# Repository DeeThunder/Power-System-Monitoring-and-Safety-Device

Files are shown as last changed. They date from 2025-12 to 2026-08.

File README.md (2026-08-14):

# Power System Monitoring and Safety Device - README

## Overview

This is a **Smart Energy Monitoring and Safety System** designed for residential areas in Nigeria. The system monitors power parameters (Voltage, Current, Power), displays data locally on an OLED screen, transmits data to the cloud via Blynk, and includes automatic safety protection that disconnects power during fault conditions.

> This project was professionally designed and implemented as a **Final Year Project (FYP)** for a client, focusing on robust industrial-grade monitoring principles and cloud-integrated data analytics.

## Features

✅ **Real-time Monitoring**: Continuous voltage, current, and power measurement  
✅ **Cloud Dashboard**: Blynk IoT integration for remote monitoring  
✅ **Cloud Logging**: Automatic logging to Google Sheets for historical data analysis  
✅ **Local Display**: 1.3" OLED screen showing live data  
✅ **Safety Protection**: Automatic relay trip on over-voltage, under-voltage, or over-current  
✅ **Offline Operation**: Continues monitoring and protection even without WiFi  
✅ **Battery Monitoring**: Track system uptime and battery health via heartbeat logging  
✅ **Visual Status**: RGB LED indicates system state  
✅ **Modular Architecture**: Clean C++ design with separated concerns  
✅ **Non-blocking**: Uses millis() timers, no delay() calls

## Hardware Components

- **Microcontroller**: ESP32 Dev Kit
- **Voltage Sensor**: ZMPT101b (simulated with potentiometer for testing)
- **Current Sensor**: SCT-013 100A CT (simulated with potentiometer for testing)
- **Relay**: 1-Channel Relay Module
- **Display**: 1.3" OLED (SSD1306, I2C)
- **Status LED**: RGB LED (Common Cathode)
- **Power Control**: Physical Boat Switch (hardware power on/off)
- **Power**: AC-DC 5V with 7.4V battery backup

## Pin Configuration

| Component | GPIO Pin | Notes |
| --- | --- | --- |
| Voltage Sensor  | GPIO 34  | ADC1_CH6 |
| Current Sensor  | GPIO 35  | ADC1_CH7 |
| Relay | GPIO 26  | Configurable Active HIGH/LOW |
| RGB LED (Red) | GPIO 25  | PWM capable |
| RGB LED (Green) | GPIO 33  | PWM capable |
| RGB LED (Blue)  | GPIO 32  | PWM capable |
| OLED SDA | GPIO 21  | I2C Data |
| OLED SCL | GPIO 22  | I2C Clock |

## Software Architecture

### Modules

1. **EnergySensor**: Handles sensor reading with calibration
2. **DisplayManager**: Manages OLED display screens
3. **NetworkManager**: WiFi and Blynk communication
4. **SafetyManager**: Threshold monitoring and relay control
5. **CloudLogger**: Automatic logging to Google Sheets
6. **PerformanceLogger**: CSV logging via Serial and cloud integration
7. **StateManager**: Finite state machine coordinating all modules

### State Machine

- **STATE_BOOT**: Initialization and WiFi connection
- **STATE_NORMAL**: Active monitoring with cloud logging
- **STATE_TRIP_PROTECTION**: Fault detected, power disconnected
- **STATE_OFFLINE_MODE**: WiFi lost, local monitoring continues

## Getting Started

Install [PlatformIO](https://platformio.org/) IDE or CLI.

### Configure Credentials

**IMPORTANT:** Create your `secrets.h` file by moving the template from the `docs` folder:

```bash
# Move the template to the include folder and rename it
copy docs/secrets.h.example include/secrets.h  # On Windows
# OR
cp docs/secrets.h.example include/secrets.h    # On Linux/Mac
```

Edit `include/secrets.h` and update your credentials:

```cpp
// WiFi Credentials
#define SECRET_WIFI_SSID      "Your_WiFi_Name"
#define SECRET_WIFI_PASSWORD  "Your_WiFi_Password"

// Blynk IoT Credentials  
#define SECRET_BLYNK_TEMPLATE_ID     "Your_Template_ID"
#define SECRET_BLYNK_TEMPLATE_NAME   "Your_Template_Name"
#define SECRET_BLYNK_AUTH_TOKEN      "Your_Blynk_Token"

// Google Sheets Logging
#define SECRET_GOOGLE_SHEETS_URL     "https://script.google.com/macros/s/YOUR_DEPLOYMENT_ID/exec"
```

> **Note:** `secrets.h` is already in `.gitignore` and will NOT be committed to version control.

### Configure Safety Thresholds

Adjust thresholds in `include/config.h`:

```cpp
#define VOLTAGE_MAX           240.0  // Over-voltage trip
#define VOLTAGE_MIN           180.0  // Under-voltage trip
#define CURRENT_MAX           20.0   // Over-current trip
```

### Build and Upload

```bash
pio run --target upload
pio device monitor
```

## Blynk Setup

> **[Click here for the detailed Step-by-Step Blynk Setup Guide](BLYNK_SETUP.md)**

### Virtual Pins

- **V0**: Voltage (read-only)
- **V1**: Current (read-only)
- **V2**: Power (read-only)
- **V3**: System State (read-only)
- **V4**: Reset Button (write)

### Datastreams

Create the following datastreams in your Blynk template:

1. V0 - Voltage (0-300V)
2. V1 - Current (0-100A)
3. V2 - Power (0-10000W)
4. V3 - State (String)
5. V4 - Reset (Integer 0-1)

## Cloud Logging (Google Sheets)

The system automatically logs performance data and system events to Google Sheets when WiFi is connected.

### Setup Google Apps Script

1. **Create a Google Sheet** named "ESP32 Performance Logs"
2. **Create 4 tabs**: `SystemEvents`, `Latency`, `Accuracy`, `TripResponse`
3. **Open Script Editor**: Extensions → Apps Script
4. **Paste the script** from `docs/google_apps_script.js`
5. **Deploy as Web App**:
   - Click Deploy → New deployment
   - Type: Web app
   - Execute as: Me
   - Who has access: Anyone
   - Click Deploy
   - **Copy the deployment URL**

### Configure in ESP32

Edit `include/config.h`:

```cpp
#define GOOGLE_SHEETS_URL "https://script.google.com/macros/s/YOUR_DEPLOYMENT_URL/exec"
#define ENABLE_CLOUD_LOGGING      // Enables automatic cloud logging
#define ENABLE_PERFORMANCE_LOGGING // Enables performance metrics
```

### What Gets Logged

**SystemEvents Tab:**
- BOOT - System startup
- HEARTBEAT - Every 5 minutes (includes WiFi RSSI for battery health monitoring)
- POWER_OUTAGE - Mains voltage lost
- POWER_RESTORED - Mains voltage restored
- TRIP - Safety faults with fault reason

**Latency Tab:**
- Sensor read time
- Blynk transmit time
- Total latency (logged on every Blynk transmission)

**Accuracy Tab:**
- Voltage, Current, Power readings
- Logged every 10 seconds

**TripResponse Tab:**
- Fault detection time
- Relay trip time
- Total response time (logged when safety trips occur)

### Battery Health Monitoring

Use heartbeat data to monitor battery health:

- **Continuous heartbeats during outage** = Healthy battery
- **Gaps in heartbeats** = Battery depleted or WiFi too weak
- **Declining RSSI** = Battery voltage dropping
- **BOOT after gap** = System shut down (battery dead)

## Calibration

After hardware assembly, calibrate sensors:

1. Connect a known voltage source (measure with multimeter)
2. Adjust `VOLTAGE_SLOPE` and `VOLTAGE_INTERCEPT` in `config.h`
3. Connect a known current load (measure with clamp meter)
4. Adjust `CURRENT_SLOPE` and `CURRENT_INTERCEPT` in `config.h`
5. Verify accuracy across operating range

## Safety Features

### Automatic Protection

The system continuously monitors power parameters every 100ms. If any threshold is exceeded:

1. Relay trips immediately (power disconnected)
2. RGB LED turns RED
3. OLED displays fault reason
4. Alert sent to Blynk (if connected)

### Reset Procedure

To reset after a trip:

1. Ensure fault condition is cleared
2. Press reset button in Blynk app

The system will only reset if readings are within safe limits.

### Offline Safety

**Critical**: Safety monitoring continues even when WiFi is disconnected. The relay will trip on fault conditions regardless of network status.

## RGB LED Status

- 🔵 **Blue**: Booting/Initializing
- 🟢 **Green**: Normal operation
- 🟡 **Yellow**: Offline mode (WiFi disconnected)
- 🔴 **Red**: Trip protection active

## Troubleshooting

### Display Not Working

- Check I2C address (0x3C or 0x3D)
- Verify SDA/SCL connections
- Check serial monitor for initialization errors

### WiFi Not Connecting

- Verify credentials in `config.h`
- Check 2.4GHz WiFi (ESP32 doesn't support 5GHz)
- Monitor serial output for connection attempts

### Blynk Not Connecting

- Verify auth token
- Ensure WiFi is connected first
- Check Blynk server status

### False Trips

- Adjust hysteresis values in `config.h`
- Calibrate sensors properly
- Check for electrical noise

## Migration to Production

To switch from simulation (potentiometers) to real sensors:

1. Remove `-D SIMULATION_MODE` from `platformio.ini`
2. Add EmonLib library
3. Update `EnergySensor.cpp` with EmonLib code
4. Recalibrate with actual sensors

## Documentation

### 📚 Complete Documentation Suite

- **[API Documentation](docs/API_DOCUMENTATION.md)** - Complete API reference, configuration guide, calibration procedures, and troubleshooting
- **[Technical Challenges Report](docs/TECHNICAL_CHALLENGES.md)** - Detailed analysis of all challenges faced and solutions implemented
- **[Blynk Setup Guide](BLYNK_SETUP.md)** - Step-by-step IoT platform configuration
- **[Hybrid Analysis Guide](docs/HYBRID_ANALYSIS_GUIDE.md)** - Guide for combining cloud and USB data for unified analysis

### Quick Links

| Topic | Document | Description |
|---|---|---|
| Getting Started | [API Documentation](docs/API_DOCUMENTATION.md#getting-started) | Installation and first-time setup |
| API Reference | [API Documentation](docs/API_DOCUMENTATION.md#api-reference) | Complete class and method documentation |
| Calibration | [API Documentation](docs/API_DOCUMENTATION.md#calibration-procedures) | Sensor calibration step-by-step |
| Troubleshooting | [API Documentation](docs/API_DOCUMENTATION.md#troubleshooting) | Common issues and solutions |
| Contributing | [API Documentation](docs/API_DOCUMENTATION.md#contributing) | Code style and contribution guidelines |
| Future Plans | [API Documentation](docs/API_DOCUMENTATION.md#future-enhancements) | Roadmap and planned features |

## License

MIT License - Free for educational and commercial use

## Support

For issues or questions, please open an issue on GitHub.

---

**⚠️ Safety Warning**: This system controls mains power. Only qualified electricians should install and wire the hardware. Improper installation can result in electric shock, fire, or death.

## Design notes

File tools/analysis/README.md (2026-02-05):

# Performance Analysis Scripts

This folder contains Python scripts for analyzing the performance data collected from the Smart Energy Monitoring System.

## Data Files

The analysis scripts process the following CSV files from the performance_data directory:
- `../../performance_data/latency.csv` - Transmission latency measurements
- `../../performance_data/accuracy.csv` - Voltage, current, and power accuracy measurements
- `../../performance_data/trip_response.csv` - Safety trip response time data

## Analysis Scripts

### 1. `latency_analysis.py`
Analyzes transmission latency metrics:
- Sensor read time distribution
- Blynk transmission delays
- Total end-to-end latency
- Temporal trends and anomaly detection
- Component breakdown and bottleneck identification

### 2. `accuracy_analysis.py`
Evaluates measurement accuracy:
- Voltage sensor calibration validation
- Current sensor accuracy assessment
- Statistical error metrics (MAE, RMSE, MAPE)
- Noise and stability analysis
- Sensor drift over time

### 3. `trip_response_analysis.py`
Assesses safety protection performance:
- Fault detection time analysis
- Relay actuation time statistics
- Total response time distribution
- Safety compliance validation
- Reliability metrics

### 4. `integrated_analysis.py`
Performs multi-metric correlation analysis:
- Relationships between latency, accuracy, and response time
- System-wide performance assessment
- Comprehensive reporting

### 5. `generate_report.py`
Generates comprehensive performance report:
- Executive summary with key findings
- Detailed analysis results
- Visualizations and charts
- Recommendations for optimization

## Requirements

Install required Python packages:
```bash
pip install pandas numpy matplotlib seaborn scipy scikit-learn
```

Or use the provided requirements file:
```bash
pip install -r requirements.txt
```

## Usage

**Note: Do not run these scripts yet until sufficient data is collected.**

Once you have adequate data:

```bash
# Run individual analyses
python latency_analysis.py
python accuracy_analysis.py
python trip_response_analysis.py

# Run integrated analysis
python integrated_analysis.py

# Generate comprehensive report
python generate_report.py
```

## Output

Analysis results will be saved in the `results/` subdirectory:
- `results/figures/` - Generated plots and visualizations
- `results/tables/` - Statistical summary tables
- `results/reports/` - Comprehensive analysis reports

## Data Collection Guidelines

For robust analysis, collect:
- **Latency data**: At least 1000 samples across different conditions
- **Accuracy data**: Reference measurements with calibrated instruments
- **Trip response data**: Multiple fault scenarios (over-voltage, under-voltage, over-current)

## Analysis Plan

Refer to `../../docs/PERFORMANCE_ANALYSIS_PLAN.md` for the complete analysis methodology and objectives.

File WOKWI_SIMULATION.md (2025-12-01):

# Wokwi Simulation Guide

## Overview

This project includes a complete Wokwi simulation that allows you to test the Smart Energy Monitoring System in your browser without physical hardware!

## Simulation Components

The simulation includes:
- ✅ **ESP32 DevKit V1**
- ✅ **SSD1306 OLED Display** (128x64, I2C)
- ✅ **2x Potentiometers** (simulating voltage and current sensors)
- ✅ **Relay Module** (1-channel)
- ✅ **RGB LED** (Common Cathode with 220Ω resistors)

## How to Run the Simulation

### Option 1: Wokwi for VS Code Extension

1. **Install Extension**:
   - Open VS Code
   - Install "Wokwi Simulator" extension
   - Restart VS Code

2. **Build Firmware**:
   ```bash
   # In VS Code terminal
   pio run
   ```

3. **Start Simulation**:
   - Press `F1` or `Ctrl+Shift+P`
   - Type "Wokwi: Start Simulator"
   - Select the project

4. **Interact**:
   - Adjust potentiometers to simulate voltage/current changes
   - Watch OLED display update
   - Observe RGB LED color changes
   - Monitor serial output

### Option 2: Wokwi CLI

1. **Install Wokwi CLI**:
   ```bash
   npm install -g @wokwi/cli
   ```

2. **Build Firmware**:
   ```bash
   pio run
   ```

3. **Run Simulation**:
   ```bash
   wokwi-cli --timeout 0
   ```

### Option 3: Wokwi Web (Manual Upload)

1. Go to [https://wokwi.com/](https://wokwi.com/)
2. Create new ESP32 project
3. Copy `diagram.json` content to the diagram editor
4. Upload your compiled firmware
5. Start simulation

## Testing Scenarios

### 1. Normal Operation Test

**Steps**:
1. Start simulation
2. Wait for OLED to show startup screen (3 seconds)
3. System should transition to NORMAL state
4. RGB LED should be **GREEN**
5. OLED should display voltage, current, and power readings

**Expected Behavior**:
- Voltage: ~180-250V (based on potentiometer position)
- Current: ~0-25A (based on potentiometer position)
- Power: Voltage × Current
- Display updates every 1 second

### 2. Over-Voltage Trip Test

**Steps**:
1. Wait for system to enter NORMAL state
2. Slowly turn the **voltage potentiometer** to maximum (right)
3. Watch for voltage reading to exceed 240V

**Expected Behavior**:
- Relay clicks (trips)
- RGB LED turns **RED**
- OLED displays "ALERT! OVER VOLTAGE"
- Serial monitor shows fault detection
- System enters TRIP_PROTECTION state

### 3. Over-Current Trip Test

**Steps**:
1. Reset simulation (or wait for Blynk reset)
2. Wait for NORMAL state
3. Turn the **current potentiometer** to maximum (right)
4. Watch for current reading to exceed 20A

**Expected Behavior**:
- Relay trips
- RGB LED turns **RED**
- OLED displays "ALERT! OVER CURRENT"
- System enters TRIP_PROTECTION state

### 4. Under-Voltage Trip Test

**Steps**:
1. Reset simulation
2. Wait for NORMAL state
3. Turn the **voltage potentiometer** to minimum (left)
4. Watch for voltage reading to drop below 180V

**Expected Behavior**:
- Relay trips
- RGB LED turns **RED**
- OLED displays "ALERT! UNDER VOLTAGE"
- System enters TRIP_PROTECTION state

### 5. Offline Mode Test

**Note**: WiFi simulation in Wokwi is limited. The system will likely enter OFFLINE_MODE automatically since there's no real WiFi network.

**Expected Behavior**:
- RGB LED turns **YELLOW**
- OLED shows "OFFLINE MODE"
- Safety monitoring continues
- System can still trip on faults

## Serial Monitor Commands

Watch the serial monitor for debug output:

```
[EnergySensor] V=220.50V, I=5.23A, P=1153.22W
[SafetyManager] All checks passed
[DisplayManager] Showing data screen
[NetworkManager] WiFi disconnected
[StateManager] State: OFFLINE_MODE
```

## Potentiometer Mapping

### Voltage Potentiometer (GPIO 34)
- **Minimum (Left)**: ~180V
- **Center**: ~215V
- **Maximum (Right)**: ~250V

### Current Potentiometer (GPIO 35)
- **Minimum (Left)**: ~0A
- **Center**: ~12.5A
- **Maximum (Right)**: ~25A

## Triggering Safety Trips

To test each safety feature:

| Fault Type | Potentiometer | Position | Threshold |
|---|---|---|---|
| Over-Voltage | Voltage | Maximum (Right) | >240V |
| Under-Voltage | Voltage | Minimum (Left) | <180V |
| Over-Current | Current | Maximum (Right) | >20A |

## Reset After Trip

Since the physical button was removed, you have two options to reset:

1. **Restart Simulation**: Stop and start the simulation
2. **Blynk Integration**: If you configure Blynk, use the V4 reset button

## Limitations in Simulation

⚠️ **What doesn't work in Wokwi**:
- WiFi connection (will always be in OFFLINE_MODE)
- Blynk communication
- Real-time cloud data logging

✅ **What works perfectly**:
- Sensor reading (via potentiometers)
- Safety threshold checking
- Relay trip mechanism
- RGB LED status indication
- OLED display updates
- State machine transitions
- Serial debug output

## Troubleshooting

### Display Not Showing
- Check I2C address in `config.h` (should be 0x3C)
- Verify OLED connections in `diagram.json`

### Relay Not Clicking
- Ensure potentiometer values exceed thresholds
- Check serial monitor for safety check messages

### RGB LED Not Changing
- Verify Common Cathode configuration in `config.h`
- Check resistor connections in diagram

### Simulation Crashes
- Reduce `ADC_SAMPLES` in `config.h` to 5 (from 10)
- Increase task intervals to reduce CPU load

## Advanced: Modifying the Simulation

### Change Voltage Range

Edit `EnergySensor.cpp`, line ~75:
```cpp
float simulatedVoltage = map(rawADC, 0, ADC_RESOLUTION, 180, 250);
//                                                        ^^^  ^^^
//                                                        min  max
```

### Change Current Range

Edit `EnergySensor.cpp`, line ~88:
```cpp
float simulatedCurrent = map(rawADC, 0, ADC_RESOLUTION, 0, 25);
//                                                       ^  ^^
//                                                      min max
```

### Add More Components

Edit `diagram.json` to add:
- Push buttons
- Additional LEDs
- LCD display
- Buzzers

## Video Recording

Wokwi allows you to record your simulation:
1. Start simulation
2. Click "Record" button
3. Perform test scenarios
4. Stop recording
5. Download video

Perfect for documentation and demonstrations!

## Next Steps

After validating in Wokwi:
1. ✅ Verify all state transitions work
2. ✅ Test safety thresholds
3. ✅ Confirm display updates
4. 🔧 Build on real hardware
5. 🔧 Calibrate with actual sensors
6. 🔧 Configure WiFi and Blynk

---

**Happy Simulating!** 🚀

For issues or questions, check the serial monitor output first - it provides detailed debug information about what the system is doing.

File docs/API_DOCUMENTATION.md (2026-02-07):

# Smart Energy Monitoring & Safety System - Complete Documentation

## Table of Contents
1. [Project Overview](#project-overview)
2. [System Architecture](#system-architecture)
3. [Getting Started](#getting-started)
4. [API Reference](#api-reference)
5. [Configuration Guide](#configuration-guide)
6. [Calibration Procedures](#calibration-procedures)
7. [Troubleshooting](#troubleshooting)
8. [Contributing](#contributing)
9. [Future Enhancements](#future-enhancements)
10. [License](#license)

---

## Project Overview

### Purpose
A real-time energy monitoring system with intelligent safety protection for AC electrical loads. The system monitors voltage and current, calculates power consumption, and automatically disconnects the load when dangerous conditions are detected.

### Key Features
- ✅ Real-time voltage and current monitoring
- ✅ Automatic over/under voltage protection
- ✅ Over-current protection with configurable thresholds
- ✅ OLED display for local monitoring
- ✅ IoT connectivity via Blynk platform
- ✅ RGB LED status indicators
- ✅ Smart power-off detection (no false trips)
- ✅ Exponential moving average filtering for stability
- ✅ Hysteresis to prevent relay chattering

### Hardware Requirements
- **Microcontroller**: ESP32 Development Board
- **Voltage Sensor**: ZMPT101B AC Voltage Sensor
- **Current Sensor**: SCT-013 Current Transformer (30A max)
- **Display**: SSD1306 128x64 OLED (I2C)
- **Relay**: 1-Channel 5V Relay Module (NO contact)
- **Status LED**: RGB LED (Common Cathode)
- **Power Supply**: 5V DC adapter

### Software Stack
- **Framework**: Arduino (PlatformIO)
- **Platform**: Espressif ESP32
- **Libraries**:
  - `Blynk` (v1.3.2) - IoT connectivity
  - `U8g2` (v2.36.15) - OLED display driver
  - `WiFi` - Built-in ESP32 WiFi
  - `Wire` - I2C communication

---

## System Architecture

### Module Overview

```
┌─────────────────────────────────────────────────────────┐
│                     Main Application                     │
│                      (main.cpp)                          │
└──────────────────────┬──────────────────────────────────┘
                       │
                       ▼
┌─────────────────────────────────────────────────────────┐
│                    State Manager                         │
│           (Finite State Machine Coordinator)             │
└─┬───────┬───────┬───────┬───────────────────────────────┘
  │       │       │       │
  ▼       ▼       ▼       ▼
┌────┐ ┌────┐ ┌────┐ ┌─────────┐
│Sensor│Display│Safety│ Network │
│Module│Module │Module│ Module  │
└────┘ └────┘ └────┘ └─────────┘
  │       │       │       │
  ▼       ▼       ▼       ▼
┌────────────────────────────────┐
│      Hardware Abstraction      │
│   (ADC, I2C, GPIO, WiFi)       │
└────────────────────────────────┘
```

### State Machine

The system operates in four distinct states:

1. **BOOT**: Initialization and WiFi connection
2. **NORMAL**: Active monitoring with cloud connectivity
3. **OFFLINE_MODE**: Local monitoring (WiFi unavailable)
4. **TRIP_PROTECTION**: Fault detected, relay disconnected

### Data Flow

```
Sensors → ADC → RMS Calculation → Smoothing → Safety Check → Relay Control
                                      ↓
                                  Display Update
                                      ↓
                                  Cloud Publish
```

---

## Getting Started

### Prerequisites

1. **Install PlatformIO**
   ```bash
   # Using VS Code
   # Install PlatformIO IDE extension from marketplace
   
   # Or using CLI
   pip install platformio
   ```

2. **Clone Repository**
   ```bash
   git clone https://github.com/yourusername/Samuel-Project.git
   cd Samuel-Project
   ```

3. **Configure Credentials**
   
   Create `include/secret.h`:
   ```cpp
   #ifndef SECRET_H
   #define SECRET_H
   
   #define SECRET_WIFI_SSID "YourWiFiSSID"
   #define SECRET_WIFI_PASSWORD "YourWiFiPassword"
   
   #endif
   ```

4. **Update Blynk Configuration**
   
   In `include/config.h`, update:
   ```cpp
   #define BLYNK_TEMPLATE_ID "YourTemplateID"
   #define BLYNK_AUTH_TOKEN "YourAuthToken"
   ```

### Building and Uploading

```bash
# Build project
pio run

# Upload to ESP32
pio run --target upload

# Open serial monitor
pio device monitor
```

### First-Time Setup

1. **Power on the system**
2. **Wait for WiFi connection** (blue LED indicates connecting)
3. **Verify display shows startup screen**
4. **Check serial monitor for initialization logs**
5. **Proceed to calibration** (see Calibration section)

---

## API Reference

### EnergySensor Class

**Purpose**: Handles voltage and current sensing with RMS calculation and filtering.

#### Public Methods

```cpp
void begin()
```
- **Description**: Initialize ADC and sensor configuration
- **Parameters**: None
- **Returns**: void
- **Usage**:
  ```cpp
  EnergySensor sensor;
  sensor.begin();
  ```

```cpp
void update()
```
- **Description**: Read sensors, calculate RMS, apply smoothing
- **Call Frequency**: Every 500ms recommended
- **Side Effects**: Updates internal voltage_ and current_ values

```cpp
float getVoltage() const
```
- **Returns**: Smoothed voltage in Volts (V)
- **Range**: 0.0 - 300.0V
- **Accuracy**: ±2% after calibration

```cpp
float getCurrent() const
```
- **Returns**: Smoothed current in Amperes (A)
- **Range**: 0.0 - 30.0A
- **Accuracy**: ±5% after calibration

```cpp
float getPower() const
```
- **Returns**: Calculated power (V × I) in Watts (W)
- **Note**: Assumes unity power factor

```cpp
bool isValid() const
```
- **Returns**: true if readings are within reasonable bounds
- **Use Case**: Validate sensor connectivity

#### Private Methods

```cpp
float readVoltageSimulation()
```
- **Algorithm**: Single-pass RMS with dynamic DC bias removal
- **Samples**: 1000 samples over ~100ms
- **Formula**: `RMS = sqrt((ΣV² - (ΣV)²/N) / N)`

```cpp
float readCurrentSimulation()
```
- **Algorithm**: Two-pass RMS (DC bias then RMS)
- **Samples**: 500 samples over ~100ms

---

### SafetyManager Class

**Purpose**: Monitors electrical parameters and controls relay for protection.

#### Public Methods

```cpp
void begin()
```
- **Description**: Initialize relay and RGB LED pins
- **Initial State**: Relay OFF, RGB Blue

```cpp
bool checkSafety(float voltage, float current)
```
- **Parameters**:
  - `voltage`: Current voltage reading (V)
  - `current`: Current current reading (A)
- **Returns**: `true` if safe, `false` if fault detected
- **Side Effects**: Sets `lastFaultReason_` on fault
- **Logic**:
  ```
  IF voltage < 100V THEN return true (power off)
  IF voltage > 250V THEN return false (over-voltage)
  IF voltage < 216V THEN return false (under-voltage)
  IF current > 30A THEN return false (over-current)
  ELSE return true
  ```

```cpp
void tripRelay()
```
- **Description**: De-energize relay (disconnect load)
- **Visual**: Sets RGB to RED
- **State**: Sets `relayTripped_ = true`

```cpp
void resetRelay()
```
- **Description**: Energize relay (connect load)
- **Precondition**: Safety conditions must be met
- **State**: Sets `relayTripped_ = false`

```cpp
bool isTripped() const
```
- **Returns**: Current relay state
- **Use Case**: Check if system is in fault state

```cpp
String getLastFaultReason() const
```
- **Returns**: "OVER VOLTAGE", "UNDER VOLTAGE", or "OVER CURRENT"
- **Use Case**: Display fault reason to user

```cpp
void setRGBStatus(uint8_t r, uint8_t g, uint8_t b)
```
- **Parameters**: RGB values (0-255)
- **Note**: Automatically inverts for common anode LEDs
- **Predefined Colors**:
  - `RGB_BLUE`: Booting/Offline
  - `RGB_GREEN`: Normal operation
  - `RGB_RED`: Fault/Trip
  - `RGB_YELLOW`: Warning (unused)

---

### DisplayManager Class

**Purpose**: Manages OLED display output for various system states.

#### Public Methods

```cpp
bool begin()
```
- **Returns**: `true` if display initialized successfully
- **Display**: SSD1306 128x64 I2C
- **Address**: 0x3C

```cpp
void showStartup()
```
- **Display**: Logo and loading bar
- **Duration**: Shown during BOOT state (~3s)

```cpp
void showData(float voltage, float current, float power, 
              bool wifiConnected, bool blynkConnected)
```
- **Layout**:
  ```
  ┌────────────────────────┐
  │ ACTIVE [WiFi][Blynk]   │
  ├────────────────────────┤
  │ VOLT                   │
  │      223.5 V           │
  ├────────────────────────┤
  │ CURR     │  PWR        │
  │ 12.5 A   │  2.8 kW     │
  └────────────────────────┘
  ```

```cpp
void showTripAlert(const String& reason)
```
- **Display**: Inverted screen with "TRIPPED!" and fault reason
- **Visual**: High contrast for attention

```cpp
void showOfflineMode()
```
- **Display**: "OFFLINE MODE" with local sensor data
- **Use Case**: WiFi disconnected

```cpp
void clear()
```
- **Description**: Clear display buffer and screen

---

### StateManager Class

**Purpose**: Coordinates all modules using finite state machine.

#### Public Methods

```cpp
void begin()
```
- **Description**: Initialize state machine
- **Initial State**: BOOT

```cpp
void update()
```
- **Description**: Execute current state logic
- **Call Frequency**: Every loop iteration
- **Non-blocking**: Uses millis() for timing

```cpp
void setState(SystemState newState)
```
- **Parameters**: `STATE_BOOT`, `STATE_NORMAL`, `STATE_OFFLINE_MODE`, `STATE_TRIP_PROTECTION`
- **Side Effects**: Calls `onStateExit()` and `onStateEnter()`

```cpp
SystemState getState() const
```
- **Returns**: Current system state

```cpp
String getStateName() const
```
- **Returns**: Human-readable state name

```cpp
void handleReset()
```
- **Description**: Handle manual reset from button or Blynk
- **Precondition**: Must be in TRIP_PROTECTION state
- **Safety Check**: Verifies conditions are safe before reset

```cpp
void handleManualSwitch(bool turnOn)
```
- **Description**: Handle manual ON/OFF control via Blynk switch (V5)
- **Parameters**:
  - `turnOn`: `true` to turn load ON, `false` to turn OFF
- **Behavior**:
  - **Turn ON**: Performs safety check first. If safe, energizes relay and sets LED to green. If unsafe, denies request and syncs switch back to OFF.
  - **Turn OFF**: Immediately de-energizes relay, sets LED to blinking orange, and sends notification.
- **State Persistence**: Manual OFF state is saved to EEPROM and restored after power loss
- **Visual Indicator**: Blinking orange LED indicates manual OFF state
- **Safety**: Cannot turn ON if conditions are unsafe

```cpp
void handleMasterOverride(bool enable)
```
- **Description**: Enable/disable Master Override mode to bypass safety protection
- **Parameters**:
  - `enable`: `true` to enable override, `false` to disable
- **⚠️ WARNING**: This bypasses ALL safety checks except extreme overcurrent (150% of max)
- **Behavior**:
  - **Enable**: 
    - Bypasses safety checks
    - Energizes relay immediately
    - Sets LED to yellow (solid)
    - Transitions from TRIP state to NORMAL/OFFLINE
    - Syncs Blynk switch to ON
    - Sends hazard warning notification
    - Periodic reminders every 30 minutes
  - **Disable**:
    - Restores safety protection
    - Checks current conditions
    - If unsafe: Trips immediately and transitions to TRIP_PROTECTION
    - If safe: Maintains relay ON, sets LED to green/blue
- **State Persistence**: Override state is saved to EEPROM and restored after power loss
- **Visual Indicator**: Yellow LED (solid) indicates override active
- **Extreme Overcurrent Protection**: Override auto-disables if current exceeds 150% of CURRENT_MAX (fire prevention)
- **Use Case**: Temporary operation during maintenance or testing when conditions are known to be outside normal limits
- **Virtual Pin**: V5 (Blynk switch)

#### State Update Methods (Private)

```cpp
void updateStateBoot()
```
- **Timing**: 3s startup delay
- **Transition**: → NORMAL (WiFi OK) or OFFLINE_MODE (timeout)

```cpp
void updateStateNormal()
```
- **Tasks**:
  - Read sensors (500ms interval)
  - Check safety (100ms interval)
  - Update display (1000ms interval)
  - Publish to Blynk (2000ms interval)
- **Transitions**:
  - → TRIP_PROTECTION (fault detected)
  - → OFFLINE_MODE (WiFi lost)

```cpp
void updateStateTripProtection()
```
- **Tasks**:
  - Continue sensor reading
  - Display fault alert
  - Publish fault to cloud
- **Transition**: → NORMAL/OFFLINE (manual reset + safe)

```cpp
void updateStateOfflineMode()
```
- **Tasks**:
  - Local monitoring continues
  - Attempt WiFi reconnection
  - Safety checks active
- **Transitions**:
  - → NORMAL (WiFi restored)
  - → TRIP_PROTECTION (fault detected)

---

### NetworkManager Class

**Purpose**: Handle WiFi and Blynk cloud connectivity.

#### Public Methods

```cpp
void begin()
```
- **Description**: Start WiFi connection
- **Non-blocking**: Connection happens in background

```cpp
void update()
```
- **Description**: Maintain WiFi and Blynk connections
- **Call Frequency**: Every loop iteration
- **Tasks**:
  - Monitor WiFi status
  - Run Blynk.run()
  - Attempt reconnection if needed

```cpp
void publishData(float voltage, float current, float power)
```
- **Description**: Send sensor data to Blynk
- **Throttling**: Internal 2s minimum interval
- **Virtual Pins**:
  - V0: Voltage
  - V1: Current
  - V2: Power

```cpp
void sendAlert(const String& message)
```
- **Description**: Send push notification via Blynk
- **Event**: "safety_alert"
- **Use Case**: Fault detection

```cpp
void updateState(const String& state)
```
- **Description**: Update system state on cloud
- **Virtual Pin**: V3

```cpp
bool isWiFiConnected() const
```
- **Returns**: WiFi connection status

```cpp
bool isBlynkConnected() const
```
- **Returns**: Blynk cloud connection status

```cpp
void setResetCallback(void (*callback)())
```
- **Description**: Register callback for Blynk reset button
- **Virtual Pin**: V4 (write)

---

## Configuration Guide

### config.h Reference

#### Pin Definitions

```cpp
// Analog Sensors (ADC1 only - ADC2 conflicts with WiFi)
#define PIN_VOLTAGE_SENSOR    34  // GPIO 34
#define PIN_CURRENT_SENSOR    35  // GPIO 35

// Digital Outputs
#define PIN_RELAY             26  // GPIO 26
#define PIN_RGB_RED           25  // GPIO 25
#define PIN_RGB_GREEN         33  // GPIO 33
#define PIN_RGB_BLUE          32  // GPIO 32

// I2C (OLED Display)
#define PIN_SDA               21  // GPIO 21
#define PIN_SCL               22  // GPIO 22
```

**⚠️ Important**: Do not use ADC2 pins (GPIO 0, 2, 4, 12-15, 25-27) for analog input when WiFi is active.

#### Safety Thresholds

```cpp
// Voltage Limits
#define VOLTAGE_MAX           250.0  // Over-voltage trip (V)
#define VOLTAGE_MIN           216.0  // Under-voltage trip (V)
#define VOLTAGE_HYSTERESIS    5.0    // Prevent chattering (V)
#define VOLTAGE_POWER_PRESENT_THRESHOLD 100.0  // Power detection (V)

// Current Limits
#define CURRENT_MAX           30.0   // Over-current trip (A)
#define CURRENT_HYSTERESIS    0.5    // Prevent chattering (A)
```

**Customization Guide**:
- **VOLTAGE_MAX**: Set to 110% of nominal voltage (e.g., 230V × 1.1 = 253V)
- **VOLTAGE_MIN**: Set to 90% of nominal voltage (e.g., 230V × 0.9 = 207V)
- **CURRENT_MAX**: Set to rated current of protected load
- **HYSTERESIS**: 2-5V for voltage, 0.5-1A for current

#### Calibration Constants

```cpp
// Voltage Sensor (ZMPT101B)
#define VOLTAGE_CALIBRATION_FACTOR  556.0  // Adjust based on calibration
#define VOLTAGE_NOISE_THRESHOLD     75.0   // Ghost voltage filter (V)

// Current Sensor (SCT-013)
#define CURRENT_NOISE_THRESHOLD     0.60   // Ghost current filter (A)
```

**Calibration Formula**:
```
Calibration Factor = Actual Value (multimeter) / Raw RMS (serial log)
```

#### Timing Intervals

```cpp
#define INTERVAL_SENSOR_READ  500    // Sensor reading (ms)
#define INTERVAL_DISPLAY      1000   // Display update (ms)
#define INTERVAL_BLYNK        2000   // Blynk publish (ms)
#define INTERVAL_SAFETY       100    // Safety check (ms) - CRITICAL
#define INTERVAL_WIFI_RETRY   30000  // WiFi reconnect (ms)
```

**Performance Tuning**:
- Decrease `INTERVAL_SAFETY` for faster fault detection (min: 50ms)
- Increase `INTERVAL_BLYNK` to reduce cloud traffic
- Adjust `INTERVAL_SENSOR_READ` based on load dynamics

---

## Calibration Procedures

### Voltage Sensor Calibration

**Required Equipment**:
- Calibrated multimeter (True RMS)
- Stable AC power source

**Procedure**:

1. **Enable Debug Logging**
   - Ensure `#define APP_DEBUG` is uncommented in code
   - Upload firmware and open serial monitor (115200 baud)

2. **Measure Reference Voltage**
   ```
   Connect multimeter to AC source
   Record reading (e.g., 228.5V)
   ```

3. **Read Raw RMS**
   ```
   Look for log line:
   [EnergySensor] Voltage RMS: 0.4105V -> 228.27V AC
                                ^^^^^^
                                This is Raw RMS
   ```

4. **Calculate Calibration Factor**
   ```
   Factor = Actual Voltage / Raw RMS
   Factor = 228.5 / 0.4105 = 556.6
   ```

5. **Update Configuration**
   ```cpp
   // In config.h
   #define VOLTAGE_CALIBRATION_FACTOR  556.6
   ```

6. **Verify**
   ```
   Re-upload firmware
   Check that displayed voltage matches multimeter
   Tolerance: ±2%
   ```

### Current Sensor Calibration

**Required Equipment**:
- Calibrated clamp meter or current meter
- Known resistive load (e.g., heater, incandescent bulb)

**Procedure**:

1. **Connect Known Load**
   ```
   Use purely resistive load (no motors/transformers)
   Measure actual current with clamp meter
   Record reading (e.g., 5.2A)
   ```

2. **Read Raw RMS**
   ```
   Check serial monitor for current RMS value
   (May need to add debug logging similar to voltage)
   ```

3. **Calculate Factor**
   ```
   Factor = Actual Current / Raw RMS
   ```

4. **Update Code**
   ```cpp
   // In EnergySensor.cpp, readCurrentSimulation()
   float calibrationFactor = 20.0;  // Update this value
   ```

5. **Test Multiple Loads**
   ```
   Verify accuracy at:
   - Low current (1-5A)
   - Medium current (5-15A)
   - High current (15-30A)
   ```

### Threshold Calibration

**Noise Floor Measurement**:

1. **Power OFF Test**
   ```
   Disconnect AC input
   Record voltage/current readings
   Should be 0.0V / 0.0A
   If not, increase NOISE_THRESHOLD
   ```

2. **Power ON Test**
   ```
   Connect normal AC
   Monitor for 5 minutes
   Record min/max voltage fluctuations
   Set VOLTAGE_MIN/MAX with margin
   ```

3. **Trip Test**
   ```
   Manually trigger each condition:
   - Over-voltage: Use variable transformer
   - Under-voltage: Reduce input voltage
   - Over-current: Connect high load
   
   Verify relay trips correctly
   Verify reset works when safe
   ```

---

## Troubleshooting

### Common Issues

#### 1. Voltage Reads 0V When Power is ON

**Symptoms**:
```
[EnergySensor] Voltage RMS: 0.0441V -> 0.00V AC
```

**Causes**:
- ZMPT101B gain too low
- Wiring issue
- Sensor not receiving AC input

**Solutions**:
1. **Check Wiring**
   ```
   ZMPT101B OUT → ESP32 GPIO 34
   ZMPT101B VCC → 5V
   ZMPT101B GND → GND
   AC Wire → ZMPT101B Input Terminals
   ```

2. **Adjust Gain**
   ```
   Turn blue potentiometer CLOCKWISE
   Monitor serial output
   Target: Raw RMS = 0.4-0.5V
   ```

3. **Verify AC Input**
   ```
   Use multimeter on ZMPT101B input
   Should read mains voltage (e.g., 230V)
   ```

#### 2. System Trips When Power is Turned OFF

**Symptoms**:
- Relay trips immediately when AC disconnected
- State changes to TRIP_PROTECTION

**Cause**:
- EMA smoothing causing slow voltage decay
- Power-present detection not working

**Solution**:
```cpp
// Verify in EnergySensor.cpp
if (rawVoltage < VOLTAGE_NOISE_THRESHOLD) {
    voltage_ = 0.0;  // Should reset immediately
}

// Verify in SafetyManager.cpp
if (voltage < VOLTAGE_POWER_PRESENT_THRESHOLD) {
    return true;  // Should skip voltage checks
}
```

#### 3. WiFi Won't Connect

**Symptoms**:
```
[NetworkManager] WiFi disconnected
System stuck in BOOT state
```

**Solutions**:
1. **Check Credentials**
   ```cpp
   // In secret.h
   #define SECRET_WIFI_SSID "CorrectSSID"  // Case-sensitive!
   #define SECRET_WIFI_PASSWORD "CorrectPassword"
   ```

2. **Check WiFi Band**
   ```
   ESP32 only supports 2.4GHz
   Ensure router has 2.4GHz enabled
   ```

3. **Increase Timeout**
   ```cpp
   // In config.h
   #define WIFI_CONNECT_TIMEOUT  30000  // Increase to 30s
   ```

#### 4. Display Not Working

**Symptoms**:
- Blank screen
- Initialization failed message

**Solutions**:
1. **Check I2C Address**
   ```cpp
   // In config.h
   #define SCREEN_ADDRESS 0x3C  // Try 0x3D if 0x3C fails
   ```

2. **Scan I2C Bus**
   ```cpp
   // Add to setup()
   Wire.begin(PIN_SDA, PIN_SCL);
   for (byte i = 0; i < 127; i++) {
       Wire.beginTransmission(i);
       if (Wire.endTransmission() == 0) {
           Serial.printf("Found device at 0x%02X\n", i);
       }
   }
   ```

3. **Check Wiring**
   ```
   SDA → GPIO 21
   SCL → GPIO 22
   VCC → 3.3V (not 5V!)
   GND → GND
   ```

#### 5. Relay Chattering

**Symptoms**:
- Relay clicks rapidly on/off
- Voltage near threshold

**Cause**:
- Insufficient hysteresis
- Noisy voltage readings

**Solutions**:
1. **Increase Hysteresis**
   ```cpp
   #define VOLTAGE_HYSTERESIS 10.0  // Increase from 5.0
   ```

2. **Increase Smoothing**
   ```cpp
   // In EnergySensor.cpp
   const float alpha = 0.1;  // Decrease from 0.2 (more smoothing)
   ```

### Debug Logging

**Enable Verbose Logging**:
```cpp
// In config.h
#define APP_DEBUG  // Uncomment this line

// For even more detail
#define DEBUG_SERIAL  // Uncomment for sensor-level logs
```

**Serial Monitor Settings**:
- Baud Rate: 115200
- Line Ending: Both NL & CR
- Filter: None

**Key Log Messages**:
```
[Main] Initialization complete
[StateManager] State transition: BOOT -> NORMAL
[EnergySensor] Voltage RMS: 0.4105V -> 228.27V AC
[SafetyManager] FAULT: Under-voltage detected (215.30V)
[NetworkManager] WiFi connected!
[NetworkManager] Published to Blynk: V=228.50, I=12.30, P=2810.95
```

---

## Contributing

### Code Style Guidelines

**Naming Conventions**:
```cpp
// Classes: PascalCase
class EnergySensor { };

// Methods: camelCase
void updateSensor();

// Private members: camelCase with trailing underscore
float voltage_;

// Constants: UPPER_SNAKE_CASE
#define VOLTAGE_MAX 250.0

// Local variables: camelCase
float currentValue;
```

**File Organization**:
```
include/
  ├── ModuleName.h      // Class declaration
  └── config.h          // Configuration constants

src/
  ├── ModuleName.cpp    // Class implementation
  └── main.cpp          // Application entry point
```

**Documentation**:
```cpp
/**
 * @brief Brief description of function
 * 
 * Detailed description if needed.
 * 
 * @param paramName Description of parameter
 * @return Description of return value
 * 
 * @note Important notes
 * @warning Warnings about usage
 */
void functionName(int paramName);
```

### Adding New Features

**1. Create Feature Branch**
```bash
git checkout -b feature/new-feature-name
```

**2. Implement Feature**
- Follow existing module structure
- Add unit tests if applicable
- Update documentation

**3. Test Thoroughly**
- Unit tests
- Integration tests
- Hardware validation

**4. Submit Pull Request**
- Clear description
- Reference any issues
- Include test results

### Module Extension Example

**Adding a New Sensor**:

1. **Create Header** (`include/NewSensor.h`):
```cpp
#ifndef NEW_SENSOR_H
#define NEW_SENSOR_H

class NewSensor {
public:
    void begin();
    void update();
    float getValue() const;
    
private:
    float value_;
    float readSensor();
};

#endif
```

2. **Implement** (`src/NewSensor.cpp`):
```cpp
#include "NewSensor.h"
#include "config.h"

void NewSensor::begin() {
    // Initialize sensor
}

void NewSensor::update() {
    value_ = readSensor();
}

float NewSensor::getValue() const {
    return value_;
}

float NewSensor::readSensor() {
    // Sensor reading logic
    return 0.0;
}
```

3. **Integrate** (`src/main.cpp`):
```cpp
#include "NewSensor.h"

NewSensor newSensor;

void setup() {
    newSensor.begin();
}

void loop() {
    newSensor.update();
    float value = newSensor.getValue();
}
```

---

## Future Enhancements

### Planned Features

#### Phase 1: Core Improvements
- [ ] **SD Card Logging**
  - Store historical data locally
  - CSV export for analysis
  - Circular buffer for memory efficiency

- [ ] **Web Server Interface**
  - Local web dashboard (ESP32 as AP)
  - Real-time graphs
  - Configuration via web UI

- [ ] **MQTT Support**
  - Alternative to Blynk
  - Home Assistant integration
  - Custom broker support

#### Phase 2: Advanced Features
- [ ] **Energy Billing**
  - kWh accumulation
  - Cost calculation
  - Monthly reports

- [ ] **Load Scheduling**
  - Time-based relay control
  - Peak/off-peak optimization
  - Programmable schedules

- [ ] **Predictive Maintenance**
  - Trend analysis
  - Anomaly detection
  - Fault prediction

#### Phase 3: Hardware Expansion
- [ ] **Multi-Channel Support**
  - Monitor multiple circuits
  - Individual protection per channel
  - Load balancing

- [ ] **Power Quality Analysis**
  - Harmonic analysis
  - Power factor measurement
  - Frequency monitoring

- [ ] **Battery Backup**
  - UPS functionality
  - Seamless switchover
  - Battery health monitoring

### Scalability Considerations

**Horizontal Scaling** (Multiple Units):
```cpp
// Assign unique device IDs
#define DEVICE_ID "UNIT_001"

// MQTT topic structure
String topic = "energy/" + String(DEVICE_ID) + "/voltage";
```

**Vertical Scaling** (More Features):
```cpp
// Modular architecture allows easy addition
class PowerQualityAnalyzer {
    // New module for advanced features
};
```

**Performance Optimization**:
- Use FreeRTOS tasks for parallel processing
- Implement DMA for ADC sampling
- Optimize display updates (dirty regions)

### Architecture Evolution

**Current**: Monolithic state machine
```
StateManager → All Modules
```

**Future**: Event-driven architecture
```
Event Bus ← Modules publish events
    ↓
Subscribers react to events
```

**Benefits**:
- Loose coupling
- Easier testing
- Plugin architecture

---

## License

This project is licensed under the MIT License - see LICENSE file for details.

---

## Support

### Documentation
- [Technical Challenges Report](docs/TECHNICAL_CHALLENGES.md)
- [Chapter 3: Methodology](docs/CHAPTER3_METHODOLOGY.md)
- [Blynk Setup Guide](BLYNK_SETUP.md)
- [Wokwi Simulation](WOKWI_SIMULATION.md)

### Contact
- **Author**: Samuel
- **Email**: [your-email@example.com]
- **GitHub**: [https://github.com/yourusername/Samuel-Project]

### Acknowledgments
- ESP32 Community
- PlatformIO Team
- Blynk Platform
- U8g2 Library Contributors

---

**Last Updated**: December 2025
**Version**: 1.0.0
**Status**: Production Ready

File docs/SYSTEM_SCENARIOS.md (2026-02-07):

# Complete System Behavior Scenarios - Updated

## Overview

This document covers **all possible scenarios** with the updated system behavior including power notifications, manual control, and offline mode.

---

## Scenario Matrix

| # | Condition | State | Relay | LED | Notifications |
|---|---|---|---|-----|---|
| 1 | Boot + No Mains | NORMAL | OFF | Green | "POWER OUTAGE" (after 3s) |
| 2 | Boot + Mains Good + WiFi | NORMAL | ON | Green | None |
| 3 | Boot + Mains Good + No WiFi | OFFLINE_MODE | ON | Blue | None |
| 4 | Normal Operation | NORMAL | ON | Green | None |
| 5 | Overvoltage (255V) | TRIP | OFF | Red | "OVER VOLTAGE" |
| 6 | Undervoltage (180V) | TRIP | OFF | Red | "UNDER VOLTAGE" |
| 7 | Overcurrent (35A) | TRIP | OFF | Red | "OVER CURRENT" |
| 8 | Power Outage During Normal | NORMAL | Current | Green | "POWER OUTAGE" (after 3s) |
| 9 | Power Restored | NORMAL | Depends | Green | "POWER RESTORED" (after 3s) |
| 10 | Manual Switch OFF | NORMAL | OFF | Orange Blink | "LOAD SWITCHED OFF" |
| 11 | Manual Switch ON | NORMAL | ON | Green | None |
| 12 | WiFi Lost During Normal | OFFLINE_MODE | Current | Blue | None |
| 13 | WiFi Restored | NORMAL | Current | Green | None |
| 14 | Manual OFF + Power Outage | NORMAL | OFF | Orange Blink | Both notifications |
| 15 | Fault + WiFi Lost | TRIP | OFF | Red | Fault notification only |
| 16 | Master Override ENABLED | NORMAL/OFFLINE | ON | Yellow | "MASTER OVERRIDE ENABLED" |
| 17 | Master Override DISABLED (Safe) | NORMAL/OFFLINE | ON | Green/Blue | "Override DISABLED" |
| 18 | Master Override DISABLED (Unsafe) | TRIP | OFF | Red | "Override DISABLED" + Fault |
| 19 | Override + Extreme Overcurrent | TRIP | OFF | Red | "CRITICAL: Extreme overcurrent" |

---

## Detailed Scenarios

### Scenario 1: System Boot with No Mains Power

**Initial Conditions**:
- ESP32 powered on (USB/backup power)
- Mains voltage = 0V
- No load connected

**Timeline**:
```
T+0s:  System boots
       State: BOOT
       LED: Yellow blinking
       Relay: OFF

T+3s:  Boot screen complete
       WiFi connecting...

T+10s: WiFi connected
       State: BOOT → NORMAL
       LED: Yellow → Green
       powerWasPresent_ = TRUE (initial)

T+11s: First voltage reading: 0V
       powerPresent = FALSE
       Power state change detected: TRUE → FALSE
       Start debounce timer

T+14s: Still 0V (debounce complete)
       Notification: "POWER OUTAGE: Mains voltage lost"
       powerWasPresent_ = FALSE
       State: NORMAL (no change)
       LED: Green (no change)
       Relay: OFF (no change)
```

**Result**:
- ✅ State: NORMAL
- ✅ Relay: OFF
- ✅ LED: Green (solid)
- ✅ Notification: "POWER OUTAGE"
- ✅ System ready, waiting for power

---

### Scenario 2: System Boot with Good Mains + WiFi

**Initial Conditions**:
- ESP32 powered on
- Mains voltage = 220V
- WiFi available

**Timeline**:
```
T+0s:  System boots
       State: BOOT
       LED: Yellow blinking

T+3s:  Boot screen complete
       WiFi connecting...

T+8s:  WiFi connected
       State: BOOT → NORMAL
       LED: Yellow → Green
       Relay: OFF → ON (energize)

T+9s:  First voltage reading: 220V
       powerPresent = TRUE
       powerWasPresent_ = TRUE (initial)
       No power state change
       No notification

T+10s: Safety check: PASS
       All readings normal
       State: NORMAL
       Relay: ON
       LED: Green
```

**Result**:
- ✅ State: NORMAL
- ✅ Relay: ON
- ✅ LED: Green (solid)
- ✅ Notification: None
- ✅ System operating normally

---

### Scenario 3: System Boot with Good Mains + No WiFi

**Initial Conditions**:
- ESP32 powered on
- Mains voltage = 220V
- WiFi not available

**Timeline**:
```
T+0s:  System boots
       State: BOOT
       LED: Yellow blinking

T+3s:  Boot screen complete
       WiFi connecting...

T+33s: WiFi timeout (30 seconds)
       State: BOOT → OFFLINE_MODE
       LED: Yellow → Blue
       Relay: OFF → ON (energize)

T+34s: First voltage reading: 220V
       powerPresent = TRUE
       powerWasPresent_ = TRUE
       No power state change
       No notification

T+35s: Safety check: PASS
       State: OFFLINE_MODE
       Relay: ON
       LED: Blue
       Local operation active
```

**Result**:
- ✅ State: OFFLINE_MODE
- ✅ Relay: ON
- ✅ LED: Blue (solid)
- ✅ Notification: None (no internet)
- ✅ Full local functionality

---

### Scenario 4: Normal Operation

**Conditions**:
- Mains: 220V (good)
- Current: 5A (normal)
- WiFi: Connected
- User: No action

**Behavior**:
```
Continuous monitoring:
  Voltage: 220V ✓
  Current: 5A ✓
  Safety: PASS ✓

State: NORMAL
Relay: ON
LED: Green (solid)
Notifications: None
Display: Shows V, I, P
Blynk: Updates every 1 second
```

**Result**:
- ✅ Everything normal
- ✅ No notifications
- ✅ Continuous monitoring

---

### Scenario 5: Overvoltage Fault

**Initial Conditions**:
- Normal operation (220V)
- Voltage suddenly rises to 255V

**Timeline**:
```
T+0s:  Voltage: 220V → 255V
       Safety check: checkOverVoltage(255V)
       255V > 249V = TRUE
       Fault detected!

T+0s:  State: NORMAL → TRIP_PROTECTION
       Relay: ON → OFF (trip)
       LED: Green → Red
       Notification: "OVER VOLTAGE"
       Blynk switch: Synced to OFF

T+1s:  Voltage still 255V
       State: TRIP_PROTECTION (stays)
       Relay: OFF (stays)
       No additional notifications
```

**Result**:
- ✅ State: TRIP_PROTECTION
- ✅ Relay: OFF (tripped)
- ✅ LED: Red (solid)
- ✅ Notification: "OVER VOLTAGE" (once)
- ✅ Requires manual reset

---

### Scenario 6: Undervoltage Fault

**Initial Conditions**:
- Normal operation (220V)
- Voltage drops to 180V (brownout)

**Timeline**:
```
T+0s:  Voltage: 220V → 180V
       Safety check:
         powerPresent = TRUE (180V >= 100V)
         checkUnderVoltage(180V)
         180V < 200V = TRUE
       Fault detected!

T+0s:  State: NORMAL → TRIP_PROTECTION
       Relay: ON → OFF (trip)
       LED: Green → Red
       Notification: "UNDER VOLTAGE"

T+1s:  Voltage still 180V
       State: TRIP_PROTECTION (stays)
       No additional notifications
```

**Result**:
- ✅ State: TRIP_PROTECTION
- ✅ Relay: OFF (tripped)
- ✅ LED: Red (solid)
- ✅ Notification: "UNDER VOLTAGE" (once)
- ✅ Requires manual reset

**Important**: If voltage drops below 100V, it's treated as power outage, not undervoltage!

---

### Scenario 7: Overcurrent Fault

**Initial Conditions**:
- Normal operation (220V, 5A)
- Current suddenly rises to 35A

**Timeline**:
```
T+0s:  Current: 5A → 35A
       Safety check: checkOverCurrent(35A)
       35A > 30A = TRUE
       Fault detected!

T+0s:  State: NORMAL → TRIP_PROTECTION
       Relay: ON → OFF (trip)
       LED: Green → Red
       Notification: "OVER CURRENT"

T+1s:  Current drops to 0A (relay OFF)
       State: TRIP_PROTECTION (stays)
       No additional notifications
```

**Result**:
- ✅ State: TRIP_PROTECTION
- ✅ Relay: OFF (tripped)
- ✅ LED: Red (solid)
- ✅ Notification: "OVER CURRENT" (once)
- ✅ Requires manual reset

---

### Scenario 8: Power Outage During Normal Operation

**Initial Conditions**:
- Normal operation (220V, 5A)
- Relay ON, LED Green
- Power suddenly disconnected

**Timeline**:
```
T+0s:  Voltage: 220V → 0V (instant)
       powerPresent: TRUE → FALSE
       Power state change detected
       Start 3-second debounce

T+1s:  Voltage: 0V (still)
       Debounce in progress...

T+2s:  Voltage: 0V (still)
       Debounce in progress...

T+3s:  Voltage: 0V (debounce complete)
       Notification: "POWER OUTAGE: Mains voltage lost"
       powerWasPresent_ = FALSE
       State: NORMAL (no change)
       Relay: Maintains position (ON)
       LED: Green (no change)

T+4s:  Voltage: 0V
       checkSafety returns TRUE (safe - power just off)
       No trip
       State: NORMAL
```

**Result**:
- ✅ State: NORMAL (no change)
- ✅ Relay: Maintains position
- ✅ LED: Green (no change)
- ✅ Notification: "POWER OUTAGE" (after 3s)
- ✅ No fault trip

---

### Scenario 9: Power Restored After Outage

**Initial Conditions**:
- Power was out (0V)
- System in NORMAL state
- Power reconnected

**Timeline**:
```
T+0s:  Voltage: 0V → 220V (instant)
       powerPresent: FALSE → TRUE
       Power state change detected
       Start 3-second debounce

T+1s:  Voltage: 220V (still)
       Debounce in progress...

T+2s:  Voltage: 220V (still)
       Debounce in progress...

T+3s:  Voltage: 220V (debounce complete)
       Notification: "POWER RESTORED: Mains voltage detected"
       powerWasPresent_ = TRUE
       Safety check: PASS (220V is good)
       State: NORMAL (no change)
       Relay: ON (energize if was ON before)
       LED: Green

T+4s:  Normal operation resumes
       All monitoring active
```

**Result**:
- ✅ State: NORMAL
- ✅ Relay: ON (if was ON before outage)
- ✅ LED: Green
- ✅ Notification: "POWER RESTORED" (after 3s)
- ✅ Normal operation resumed

---

### Scenario 10: Manual Switch OFF via Blynk

**Initial Conditions**:
- Normal operation (220V, 5A)
- Relay ON, LED Green
- User presses OFF in Blynk app

**Timeline**:
```
T+0s:  Blynk command received: VPIN_MANUAL_SWITCH = 0
       handleManualSwitch(false) called

T+0s:  Relay: ON → OFF (de-energize)
       LED: Green → Orange (blinking)
       Notification: "LOAD SWITCHED OFF: Manual control via Blynk"
       State: NORMAL (no change)

T+1s:  Voltage: 220V (still monitored)
       Current: 0A (relay OFF)
       Safety: Still active
       State: NORMAL
       LED: Orange blinking
       Relay: OFF
```

**Result**:
- ✅ State: NORMAL (no change)
- ✅ Relay: OFF
- ✅ LED: Orange (blinking)
- ✅ Notification: "LOAD SWITCHED OFF"
- ✅ Safety monitoring continues

---

### Scenario 11: Manual Switch ON via Blynk

**Initial Conditions**:
- Load manually OFF (orange blinking)
- Mains good (220V)
- User presses ON in Blynk app

**Timeline**:
```
T+0s:  Blynk command received: VPIN_MANUAL_SWITCH = 1
       handleManualSwitch(true) called

T+0s:  Safety check performed:
       Voltage: 220V ✓
       Current: 0A ✓
       checkSafety: PASS

T+0s:  Relay: OFF → ON (energize)
       LED: Orange blinking → Green (solid)
       Stop blinking
       State: NORMAL (no change)
       No notification (normal operation resumed)

T+1s:  Current: 5A (load drawing power)
       Normal operation
```

**Result**:
- ✅ State: NORMAL
- ✅ Relay: ON
- ✅ LED: Green (solid)
- ✅ Notification: None
- ✅ Normal operation

**If Unsafe**:
```
T+0s:  Safety check: FAIL (e.g., voltage = 255V)
       Relay: Stays OFF
       Blynk switch: Synced back to OFF
       LED: Stays orange blinking
       State: NORMAL (no change)
       User cannot turn ON until safe
```

---

### Scenario 12: WiFi Lost During Normal Operation

**Initial Conditions**:
- Normal operation (220V, 5A)
- WiFi connected
- WiFi suddenly disconnects

**Timeline**:
```
T+0s:  WiFi connection lost
       network_.isWiFiConnected() = FALSE

T+0s:  State: NORMAL → OFFLINE_MODE
       LED: Green → Blue
       Relay: Maintains state (ON)
       No notification (no internet to send)

T+1s:  Local operation continues:
       Voltage monitoring: Active
       Current monitoring: Active
       Safety checks: Active
       Display: Active
       Blynk: Disconnected

T+2s:  If fault occurs:
       Safety will still trip
       LED: Blue → Red
       Relay: OFF
       No notification (no internet)
```

**Result**:
- ✅ State: OFFLINE_MODE
- ✅ Relay: Maintains state
- ✅ LED: Blue (solid)
- ✅ Notification: None (no internet)
- ✅ Full local functionality

---

### Scenario 13: WiFi Restored

**Initial Conditions**:
- System in OFFLINE_MODE
- WiFi reconnects

**Timeline**:
```
T+0s:  WiFi connection restored
       network_.isWiFiConnected() = TRUE

T+0s:  State: OFFLINE_MODE → NORMAL
       LED: Blue → Green
       Relay: Maintains state
       Blynk: Reconnecting...

T+2s:  Blynk connected
       Data sync to Blynk
       Remote control available
       Normal operation
```

**Result**:
- ✅ State: NORMAL
- ✅ Relay: Maintains state
- ✅ LED: Green
- ✅ Notification: None
- ✅ Online operation resumed

---

### Scenario 14: Manual OFF + Power Outage (Combined)

**Initial Conditions**:
- User manually switched OFF (orange blinking)
- Power then goes out

**Timeline**:
```
T+0s:  User presses OFF
       Relay: OFF
       LED: Orange blinking
       State: NORMAL
       Notification: "LOAD SWITCHED OFF: Manual control via Blynk"

T+10s: Power goes out (220V → 0V)
       powerPresent: TRUE → FALSE
       Start debounce

T+13s: Still 0V (debounce complete)
       Notification: "POWER OUTAGE: Mains voltage lost"
       State: NORMAL (no change)
       Relay: OFF (already OFF)
       LED: Orange blinking (no change)

T+20s: Power restored (0V → 220V)
       powerPresent: FALSE → TRUE
       Start debounce

T+23s: Still 220V (debounce complete)
       Notification: "POWER RESTORED: Mains voltage detected"
       State: NORMAL (no change)
       Relay: OFF (still manually OFF)
       LED: Orange blinking (still)
```

**Result**:
- ✅ State: NORMAL (throughout)
- ✅ Relay: OFF (manual control maintained)
- ✅ LED: Orange blinking (throughout)
- ✅ Notifications: All 3 sent
  1. "LOAD SWITCHED OFF"
  2. "POWER OUTAGE"
  3. "POWER RESTORED"

**Key Point**: Manual OFF state is preserved through power outage/restoration

---

### Scenario 15: Fault + WiFi Lost (Combined)

**Initial Conditions**:
- Normal operation
- Overvoltage occurs (255V)
- WiFi also disconnects

**Timeline**:
```
T+0s:  Voltage: 220V → 255V
       Fault detected: OVER VOLTAGE
       State: NORMAL → TRIP_PROTECTION
       Relay: OFF
       LED: Red
       Notification: "OVER VOLTAGE" (sent before WiFi lost)

T+1s:  WiFi disconnects
       State: TRIP_PROTECTION (no change)
       LED: Red (no change)
       Relay: OFF (no change)
       Note: Cannot transition to OFFLINE_MODE (fault takes priority)

T+10s: WiFi reconnects
       State: TRIP_PROTECTION (still)
       LED: Red (still)
       Relay: OFF (still)
       User must reset to clear fault

T+15s: User presses RESET
       Safety check: Voltage still 255V
       Reset DENIED (unsafe)
       State: TRIP_PROTECTION (stays)
```

**Result**:
- ✅ State: TRIP_PROTECTION (fault priority)
- ✅ Relay: OFF
- ✅ LED: Red
- ✅ Notification: "OVER VOLTAGE" (if sent before WiFi lost)
- ✅ Fault must be cleared before normal operation

---

### Scenario 16: Master Override ENABLED from TRIP State

**Initial Conditions**:
- System in TRIP_PROTECTION (e.g., overvoltage fault)
- Voltage still unsafe (255V)
- User enables Master Override via Blynk

**Timeline**:
```
T+0s:  System in TRIP_PROTECTION
       Voltage: 255V (unsafe)
       Relay: OFF
       LED: Red
       State: TRIP_PROTECTION

T+1s:  User enables Master Override (V5 = 1)
       handleMasterOverride(true) called
       
T+1s:  Override activated:
       isOverrideActive_ = true
       Safety checks BYPASSED
       Relay: OFF → ON (energize)
       LED: Red → Yellow
       State: TRIP_PROTECTION → NORMAL (or OFFLINE_MODE)
       Blynk switch: Synced to ON
       Notification: "⚠️ MASTER OVERRIDE ENABLED - Safety protection BYPASSED!"
       State display: "SAFETY BYPASSED"

T+2s:  System operates with override:
       Voltage: 255V (still unsafe, but allowed)
       Current: Reading actual load
       Relay: ON
       LED: Yellow (solid)
       Safety checks: BYPASSED (except extreme overcurrent)
       
T+30min: Periodic warning sent:
       Notification: "⚠️ REMINDER: Master Override is ACTIVE"
```

**Result**:
- ✅ State: NORMAL (or OFFLINE_MODE if no WiFi)
- ✅ Relay: ON (energized despite unsafe voltage)
- ✅ LED: Yellow (solid) - indicates override active
- ✅ Blynk switch: ON
- ✅ Safety protection: BYPASSED
- ✅ Periodic warnings: Every 30 minutes
- ⚠️ **WARNING**: System operates outside safe limits!

---

### Scenario 17: Master Override DISABLED (Safe Conditions)

**Initial Conditions**:
- Master Override active (yellow LED)
- Voltage: 220V (safe)
- Current: 5A (safe)
- User disables override

**Timeline**:
```
T+0s:  Override active:
       Voltage: 220V ✓
       Current: 5A ✓
       Relay: ON
       LED: Yellow
       State: NORMAL

T+1s:  User disables Master Override (V5 = 0)
       handleMasterOverride(false) called
       
T+1s:  Safety check performed:
       checkSafety(220V, 5A) = TRUE
       Conditions are SAFE
       
T+1s:  Override deactivated:
       isOverrideActive_ = false
       Relay: ON (stays ON - conditions safe)
       LED: Yellow → Green (normal operation)
       State: NORMAL (no change)
       Blynk switch: ON (no change)
       Notification: "✅ Master Override DISABLED - Safety protection restored"
       State display: "NORMAL"

T+2s:  Normal operation resumes:
       Safety checks: ACTIVE
       All protection enabled
       LED: Green
```

**Result**:
- ✅ State: NORMAL
- ✅ Relay: ON (conditions safe)
- ✅ LED: Green (normal operation restored)
- ✅ Blynk switch: ON
- ✅ Safety protection: RESTORED
- ✅ No trip (conditions were safe)

---

### Scenario 18: Master Override DISABLED (Unsafe Conditions)

**Initial Conditions**:
- Master Override active (yellow LED)
- Voltage: 255V (unsafe - overvoltage)
- Current: 10A
- User disables override

**Timeline**:
```
T+0s:  Override active:
       Voltage: 255V (unsafe)
       Current: 10A
       Relay: ON
       LED: Yellow
       State: NORMAL

T+1s:  User disables Master Override (V5 = 0)
       handleMasterOverride(false) called
       
T+1s:  Safety check performed:
       checkSafety(255V, 10A) = FALSE
       Overvoltage detected!
       
T+1s:  IMMEDIATE TRIP:
       isOverrideActive_ = false
       Relay: ON → OFF (trip immediately)
       LED: Yellow → Red
       State: NORMAL → TRIP_PROTECTION
       Blynk switch: ON → OFF (synced)
       Notification 1: "✅ Master Override DISABLED - Safety protection restored"
       Notification 2: "OVER VOLTAGE" (fault detected)

T+2s:  System in fault state:
       Relay: OFF
       LED: Red
       State: TRIP_PROTECTION
       Requires manual reset when safe
```

**Result**:
- ✅ State: TRIP_PROTECTION
- ✅ Relay: OFF (tripped immediately)
- ✅ LED: Red (fault state)
- ✅ Blynk switch: OFF (synced)
- ✅ Safety protection: RESTORED
- ✅ Fault detected and handled correctly
- ⚠️ System will not reset until voltage is safe

---

### Scenario 19: Override + Extreme Overcurrent (Auto-Disable)

**Initial Conditions**:
- Master Override active (yellow LED)
- Voltage: 220V
- Current suddenly spikes to 50A (extreme)

**Timeline**:
```
T+0s:  Override active:
       Voltage: 220V
       Current: 5A
       Relay: ON
       LED: Yellow
       State: NORMAL

T+1s:  Extreme overcurrent occurs:
       Current: 5A → 50A (fire hazard!)
       Safety check detects: 50A > 45A (150% of 30A max)
       
T+1s:  CRITICAL AUTO-TRIP:
       Override AUTO-DISABLED (safety override)
       isOverrideActive_ = false
       Relay: ON → OFF (trip immediately)
       LED: Yellow → Red
       State: NORMAL → TRIP_PROTECTION
       Blynk switch: ON → OFF (synced)
       Notification: "🔥 CRITICAL: Extreme overcurrent detected! Tripping despite override."

T+2s:  System in fault state:
       Relay: OFF
       LED: Red
       State: TRIP_PROTECTION
       Override: DISABLED (auto-disabled)
       Requires manual intervention
```

**Result**:
- ✅ State: TRIP_PROTECTION
- ✅ Relay: OFF (tripped for safety)
- ✅ LED: Red (critical fault)
- ✅ Override: AUTO-DISABLED (safety feature)
- ✅ Blynk switch: OFF (synced)
- ⚠️ **CRITICAL**: Override cannot bypass extreme overcurrent (fire prevention)
- ⚠️ Threshold: 150% of CURRENT_MAX (45A for 30A max)

---

## State Priority

When multiple conditions occur simultaneously:

```
1. TRIP_PROTECTION (highest priority)
   - Fault conditions always take precedence
   - Cannot be overridden by WiFi state

2. Manual Control
   - User can turn OFF in any state
   - User can turn ON only if safe

3. OFFLINE_MODE
   - Only if no faults present
   - Only if WiFi disconnected

4. NORMAL
   - Default operational state
```

---

## Notification Frequency Summary

| Notification | Frequency | Debounce |
|---|---|---|
| POWER OUTAGE | Once per outage | 3 seconds |
| POWER RESTORED | Once per restoration | 3 seconds |
| OVER VOLTAGE | Once per trip | None |
| UNDER VOLTAGE | Once per trip | None |
| OVER CURRENT | Once per trip | None |
| LOAD SWITCHED OFF | Once per manual OFF | None |

**Key**: All notifications sent **once per event**, not continuously.

---

## LED Behavior Summary

| LED Color | Blinking | State | Meaning |
|---|---|---|---|
| Yellow | Yes | BOOT | Starting up |
| Green | No | NORMAL | Normal operation, online |
| Orange | Yes | NORMAL (manual OFF) | Load manually switched OFF |
| Red | No | TRIP_PROTECTION | Fault condition |
| Blue | No | OFFLINE_MODE | No internet, local operation |
| Yellow | No | NORMAL/OFFLINE (override) | Master Override ACTIVE - Safety BYPASSED |

---

## Summary

This document covers **all 15 major scenarios** including:
- ✅ Power states (on, off, outage, restoration)
- ✅ Fault conditions (overvoltage, undervoltage, overcurrent)
- ✅ Manual control (ON, OFF)
- ✅ Internet connectivity (online, offline)
- ✅ Combined scenarios

**System behavior is consistent, predictable, and safe in all cases.**

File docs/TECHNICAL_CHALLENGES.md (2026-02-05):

# Technical Challenges Report: Energy Monitoring & Safety System

## Project Overview
Development of an ESP32-based energy monitoring system with safety trip protection using ZMPT101B voltage sensor and SCT-013 current sensor.

---

## Challenge 1: Persistent Under-Voltage Trip Alerts

### Problem Description
The system continuously triggered "UNDER VOLTAGE" alerts even when mains voltage was normal (228V according to multimeter).

### Root Cause
- Initial calibration factor (550.0) was too low
- Device readings showed ~216V while actual voltage was 228V
- Readings fell below the `VOLTAGE_MIN` threshold (216V), causing false trips

### Solution Implemented
- Added debug logging to display actual sensor readings
- Calculated correct calibration factor: `Real Voltage / Raw RMS = 228 / 0.41 ≈ 556`
- Updated `VOLTAGE_CALIBRATION_FACTOR` from 550.0 → 583.0 → 607.0 → 621.0 → 556.0

### Lessons Learned
- Calibration must be done with actual multimeter readings, not assumptions
- Raw sensor values (RMS) are essential for accurate calibration
- Iterative calibration is necessary as hardware changes affect readings

---

## Challenge 2: Ghost Voltage Readings When Mains OFF

### Problem Description
When mains power was disconnected, the sensor read ~64V instead of 0V.

### Root Cause
- Electrical noise and EMI picked up by the sensor circuit
- Hardcoded noise threshold (50V) was too low to filter out this interference

### Solution Implemented
- Increased `VOLTAGE_NOISE_THRESHOLD` from 50V to 75V
- Added noise gate logic: readings below threshold are set to 0V
- Implemented dynamic DC bias calculation instead of assuming fixed 2.5V center point

### Lessons Learned
- AC sensors are susceptible to environmental noise
- Noise thresholds must be calibrated based on actual environmental conditions
- Never assume fixed DC bias in real-world analog circuits

---

## Challenge 3: Static Current Reading (15A Constant)

### Problem Description
Current sensor showed constant 15A regardless of actual load or whether circuit was energized.

### Root Cause
- Simulation mode was using `map()` function to generate fake data
- Code was: `map(rawADC, 0, 4095, 0, 25)` which linearly mapped any noise to 0-25A range
- No actual RMS calculation was being performed

### Solution Implemented
- Rewrote `readCurrentSimulation()` to use proper RMS calculation
- Implemented two-pass algorithm:
  - Pass 1: Calculate DC bias (mean of samples)
  - Pass 2: Calculate RMS relative to DC bias
- Added `CURRENT_NOISE_THRESHOLD` (0.60A) to filter residual noise

### Lessons Learned
- Simulation/test code must still implement correct algorithms
- RMS calculation requires removing DC offset before computing root-mean-square
- Current sensors (SCT-013) require same mathematical rigor as voltage sensors

---

## Challenge 4: Voltage Reading Fluctuations

### Problem Description
Voltage readings fluctuated wildly (211V → 223V → 215V), causing intermittent trips.

### Root Cause Analysis
1. **Hardcoded DC Bias**: Code assumed signal centered at 2.5V, but actual center drifted
2. **Two-Pass Timing Error**: Measuring DC bias in first 100ms, then RMS in second 100ms allowed signal changes between passes
3. **ESP32 ADC Noise**: WiFi activity and other processes introduced timing jitter

### Solution Implemented
**Phase 1: Dynamic DC Bias**
- Replaced hardcoded 2.5V with calculated mean from actual samples
- Reduced errors from DC drift

**Phase 2: Single-Pass Algorithm**
- Implemented true RMS formula: `RMS = sqrt((SumSq - (Sum²/N)) / N)`
- Calculates mean and RMS simultaneously in one sampling loop
- Doubled sample count (500 → 1000) for better averaging
- Used double precision for intermediate calculations to prevent overflow

**Phase 3: Exponential Moving Average (EMA)**
- Added smoothing filter: `smoothed = 0.2 × new + 0.8 × old`
- Reduced impact of transient spikes

### Lessons Learned
- Multi-pass algorithms are vulnerable to timing errors in real-time systems
- Single-pass algorithms are more robust for AC signal processing
- Smoothing filters must be carefully tuned to balance responsiveness vs. stability

---

## Challenge 5: False Trips During Intentional Power-Off

### Problem Description
System entered TRIP state when user turned off mains power, requiring manual reset even after power restoration.

### Root Cause
Safety logic couldn't distinguish between:
- **Intentional power-off**: 0V (normal user action)
- **Brown-out fault**: 200V during operation (actual fault)

Both triggered `voltage < VOLTAGE_MIN` condition.

### Solution Implemented
**Power Present Detection**
```c
#define VOLTAGE_POWER_PRESENT_THRESHOLD 100.0
```

Modified `SafetyManager::checkSafety()`:
1. If `voltage < 100V`: Power is OFF → Skip voltage checks → Return safe
2. If `voltage > 100V`: Power is ON → Check normal limits (216-244V)

### Lessons Learned
- Safety systems must consider operational context, not just absolute thresholds
- State machines need to distinguish between normal state transitions and fault conditions
- User experience matters: false alarms reduce trust in safety systems

---

## Challenge 6: EMA Smoothing Causing Delayed Power-Off Detection

### Problem Description
After implementing EMA smoothing, turning off power caused trips during the voltage decay period (228V → 180V → 140V → 100V → 0V).

### Root Cause
- EMA filter has exponential decay with time constant τ = 1/α
- With α = 0.2, decay takes ~5 time constants ≈ 5 seconds
- During decay, voltage passed through the trip zone (100-216V)

### Solution Implemented
Modified smoothing logic to reset immediately when raw voltage drops below noise threshold:
```cpp
if (rawVoltage < VOLTAGE_NOISE_THRESHOLD) {
    voltage_ = 0.0;  // Immediate reset
} else {
    voltage_ = 0.2 × rawVoltage + 0.8 × voltage_;  // Normal smoothing
}
```

### Lessons Learned
- Smoothing filters must handle edge cases (power on/off transitions)
- Filters designed for steady-state operation may fail during transients
- Hybrid approaches (immediate reset + gradual smoothing) provide best results

---

## Challenge 7: ZMPT101B Gain Calibration Issues

### Problem Description
After adjusting physical potentiometer, raw RMS dropped to 0.04-0.06V, causing all readings to be zeroed out by noise gate.

### Root Cause
- User reduced gain too much trying to prevent signal clipping
- Raw RMS × Calibration Factor < Noise Threshold → All readings zeroed

### Ongoing Investigation
- Potentiometer adjustment had no effect on readings
- Possible causes:
  - Wrong potentiometer being adjusted (gain vs. offset)
  - Wiring issue between ZMPT101B and ESP32
  - Insufficient AC input to ZMPT101B
  - Damaged sensor

### Lessons Learned
- Hardware calibration requires clear documentation of which controls affect what
- Software should provide diagnostic feedback during hardware adjustment
- Sensor validation should be performed before software calibration

---

## Challenge 8: Blynk Push Notifications Not Received

### Problem Description
Events appeared in Blynk timeline but push notifications were not received on mobile device.

### Root Cause
- Blynk Console event `safety_alert` existed but "Send push notification" checkbox was unchecked
- Event was configured to send to timeline only, not push notifications
- Phone notification permissions may also have been disabled

### Solution Implemented
**Blynk Console Configuration**:
- Enabled "Send push notification" for `safety_alert` event
- Enabled "Send to device owner"
- Configured notification title and body

**Phone Settings Verification**:
- Android: Enabled notifications, disabled battery optimization for Blynk
- iOS: Enabled notifications, background app refresh

**Test Button Added**:
- Created `VPIN_TEST_ALERT` (V10) for manual notification testing
- Added handler in `NetworkManager.cpp` to trigger test notifications
- Allows verification without causing actual system trips

### Lessons Learned
- Blynk events require explicit push notification enablement
- Timeline and push notifications are separate configuration options
- Test mechanisms are essential for debugging notification systems
- Phone-level permissions can block app notifications

---

## Challenge 9: ZMPT101B Voltage Reading Instability

### Problem Description
ZMPT101B gave unstable/fluctuating RMS voltage readings even when multimeter showed constant voltage.

### Root Cause Analysis
1. **Insufficient Samples**: Only 1000 samples not covering enough AC cycles
2. **Fast Sampling**: 100μs delay causing aliasing with 50Hz AC signal
3. **No Outlier Rejection**: Single noisy reading affected result
4. **Single Measurement**: No averaging across multiple readings

### Solution Implemented
**Enhanced RMS Calculation**:
```cpp
- Samples: 1000 → 2000 (covers 20 complete AC cycles @ 50Hz)
- Timing: 100μs → 200μs (5kHz sampling rate, proper for 50Hz)
- Multi-reading: 5 readings with median filter
- Outlier rejection: Median of 5 eliminates spikes
```

**Configuration Parameters** (in `config.h`):
```cpp
#define VOLTAGE_NUM_SAMPLES         2000
#define VOLTAGE_NUM_READINGS        5
#define VOLTAGE_SAMPLE_DELAY_US     200
```

### Lessons Learned
- AC voltage measurement requires covering multiple complete cycles
- Sampling rate must avoid aliasing (Nyquist theorem)
- Median filtering superior to averaging for rejecting outliers
- Configurable parameters allow field tuning without code changes

---

## Challenge 10: Power Outage Triggering Undervoltage Trip

### Problem Description
When mains power went out (voltage = 0V), system incorrectly triggered "UNDER VOLTAGE" trip instead of recognizing normal power outage.

### Root Cause
`checkUnderVoltage()` function checked if voltage < 200V without first verifying power was actually present. When voltage = 0V, it satisfied the undervoltage condition and triggered a fault.

### Solution Implemented
**Modified `checkUnderVoltage()` in `SafetyManager.cpp`**:
```cpp
bool SafetyManager::checkUnderVoltage(float voltage) {
    // Only check undervoltage if power is actually present
    if (voltage < VOLTAGE_POWER_PRESENT_THRESHOLD) {  // 100V
        return false;  // Not a fault - power is just off
    }
    
    // Power is present - now check if it's too low
    if (voltage < VOLTAGE_MIN) {  // 200V
        return true;  // Actual undervoltage fault
    }
}
```

**Voltage Ranges**:
- 0-100V: Power outage (normal, no trip)
- 100-200V: Undervoltage (fault, trip)
- 200-249V: Normal voltage
- 249V+: Overvoltage (fault, trip)

### Lessons Learned
- Fault detection must distinguish between absence of power and low power
- Context-aware safety checks prevent false alarms
- Clear threshold definitions improve system reliability

---

## Challenge 11: Power Outage/Restoration Notification System

### Problem Description
Users had no visibility into mains power status - didn't know when power went out or was restored.

### Requirements
- Notify when mains power goes out (voltage drops below 100V)
- Notify when mains power is restored (voltage rises above 100V)
- Prevent notification spam from voltage fluctuations
- Work independently of system state

### Solution Implemented
**Power State Tracking** (in `SafetyManager.h`):
```cpp
bool powerWasPresent_;
unsigned long lastPowerChangeTime_;
void (*powerStateCallback)(bool powerPresent) = nullptr;
```

**Debounced State Detection** (in `SafetyManager.cpp`):
- 3-second debounce prevents false alerts from transient voltage changes
- Only sends notification when power state has been stable for 3 seconds
- Callback mechanism allows `StateManager` to send Blynk notifications

**Notification Messages**:
- Power out: "POWER OUTAGE: Mains voltage lost"
- Power restored: "POWER RESTORED: Mains voltage detected"

### Lessons Learned
- Debouncing essential for reliable state change detection
- Callback pattern allows separation of detection and notification logic
- Power awareness improves user experience and system transparency

---

## Challenge 12: State Management and Manual Control Confusion

### Problem Description
Incorrect state transitions when user manually switched load OFF via Blynk - system was going to OFFLINE_MODE instead of staying in NORMAL state.

### Root Cause
Misunderstanding of state purposes:
- OFFLINE_MODE was being used for manual switch OFF
- Actual purpose: OFFLINE_MODE should only be for no internet connection

### Solution Implemented
**Corrected State Behavior**:

| Action | State | Relay | LED | Notification |
|---|---|---|-----|---|
| Manual Switch OFF | NORMAL | OFF | Orange Blinking | "LOAD SWITCHED OFF" |
| No Internet | OFFLINE_MODE | Works Locally | Blue | None |

**Manual Switch OFF** (in `StateManager.cpp`):
```cpp
handleManualSwitch(false) {
    safety_.tripRelay();  // Relay OFF
    safety_.setRGBStatus(RGB_ORANGE);  // Orange LED
    safety_.setBlinking(true);  // Blink
    network_.sendAlert("LOAD SWITCHED OFF: Manual control via Blynk");
    // State remains unchanged (NORMAL)
}
```

**OFFLINE_MODE Purpose**:
- Only activates when WiFi/internet connection is lost
- Full local functionality maintained (monitoring, safety, relay control)
- No Blynk control or data transmission
- Blue LED indicates offline status

### Lessons Learned
- State names must clearly reflect their purpose
- Manual control should not change system operational state
- LED colors provide intuitive status feedback
- Notifications inform users of manual actions

---

## Summary of Solutions Implemented

| Challenge | Solution | Files Modified |
|---|---|---|
| Under-voltage trips | Calibration factor adjustment | `config.h` |
| Ghost voltage readings | Noise threshold + dynamic DC bias | `config.h`, `EnergySensor.cpp` |
| Static current reading | Proper RMS calculation | `EnergySensor.cpp` |
| Voltage fluctuations | Single-pass RMS + EMA smoothing | `EnergySensor.cpp` |
| False power-off trips | Power present detection | `config.h`, `SafetyManager.cpp` |
| EMA decay trips | Conditional smoothing reset | `EnergySensor.cpp` |
| Relay state visibility | Added relay status to logs | `StateManager.cpp` |
| Blynk updates during trip | Added publishData to trip state | `StateManager.cpp` |
| **Blynk push notifications** | **Enabled push in Console + test button** | **`NetworkManager.cpp`, `config.h`** |
| **ZMPT101B instability** | **Enhanced RMS: 2000 samples, median filter** | **`EnergySensor.cpp`, `config.h`** |
| **Power outage false trips** | **Power-present check in undervoltage** | **`SafetyManager.cpp`** |
| **Power state notifications** | **Debounced state tracking + callbacks** | **`SafetyManager.h/cpp`, `StateManager.cpp`** |
| **State management confusion** | **Corrected OFFLINE_MODE purpose** | **`StateManager.cpp`** |

---

## Key Technical Insights

### AC Signal Processing
1. **RMS Calculation**: Must remove DC bias before computing root-mean-square
2. **Sampling**: Minimum 500 samples over multiple AC cycles (50Hz = 20ms period)
3. **Precision**: Use double precision for intermediate calculations to prevent overflow

### Sensor Calibration
1. **Formula**: `Calibration Factor = Real Value / Raw RMS`
2. **Process**: Measure with calibrated reference → Read raw sensor → Calculate factor
3. **Iteration**: Hardware changes require recalibration

### Safety System Design
1. **Context Awareness**: Distinguish between faults and normal state transitions
2. **Hysteresis**: Prevent chattering with separate trip and reset thresholds
3. **User Experience**: Minimize false alarms while maintaining protection

### Embedded Systems
1. **Timing**: Single-pass algorithms more robust than multi-pass in real-time systems
2. **Filtering**: Balance between noise rejection and responsiveness
3. **Diagnostics**: Raw sensor logging essential for debugging and calibration

---

## Recommendations for Future Work

1. **Hardware Validation Suite**: Automated tests to verify sensor connectivity and basic operation
2. **Calibration Wizard**: Step-by-step UI to guide users through sensor calibration
3. **Adaptive Thresholds**: Machine learning to adjust noise thresholds based on environment
4. **Redundant Sensors**: Multiple voltage sensors for cross-validation
5. **Waveform Capture**: Store raw ADC samples for post-analysis of trip events
6. **Self-Test Mode**: Periodic verification of sensor operation without tripping

---

## Conclusion

This project demonstrated the complexity of real-world embedded systems development, where theoretical algorithms must be adapted to handle hardware imperfections, environmental noise, and user interaction patterns. The iterative problem-solving process—from initial debug logging through algorithm optimization to user experience refinement—highlights the importance of systematic debugging, comprehensive testing, and maintaining flexibility to revise assumptions when confronted with empirical data.

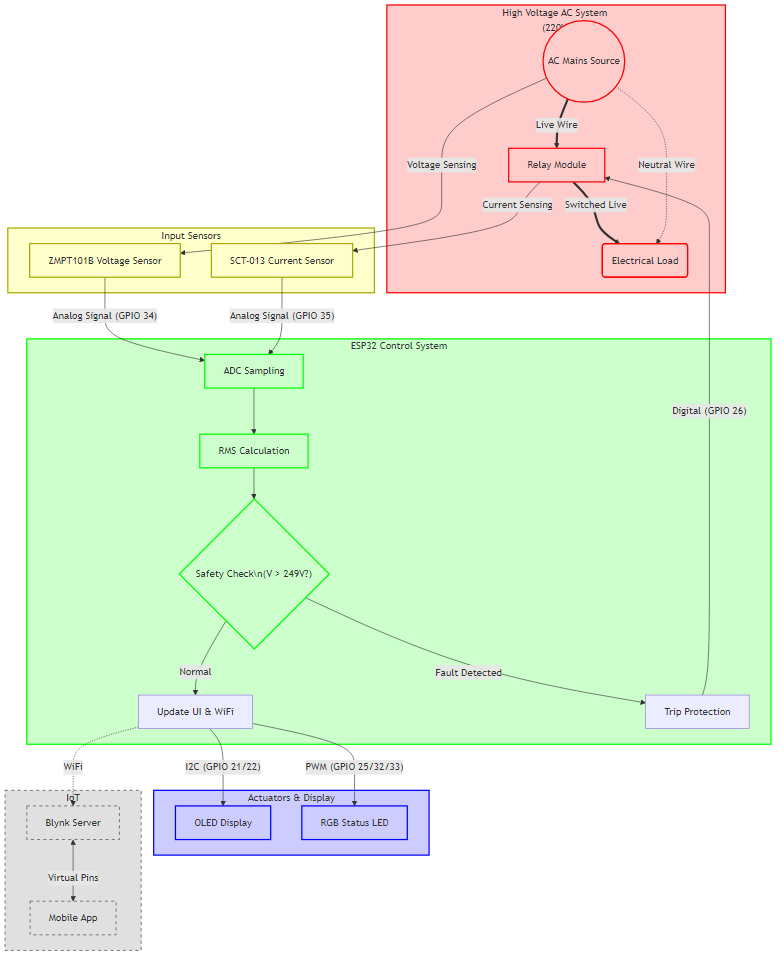
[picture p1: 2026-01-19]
docs/system_architecture.png

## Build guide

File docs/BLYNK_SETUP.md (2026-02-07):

# Blynk Setup Guide for Smart Energy Monitor

This guide will help you set up the Blynk IoT dashboard to monitor your Energy System remotely.

## Prerequisites

1.  **Blynk Account:** Create an account at [blynk.io](https://blynk.io) or log in.
2.  **Blynk Mobile App:** Download the Blynk IoT app on your smartphone (iOS or Android).

## Step 1: Create a New Template

1.  Log in to the **Blynk Console** (Web Dashboard).
2.  Go to **Templates** -> **+ New Template**.
3.  **Name:** `Energy Monitor`
4.  **Hardware:** `ESP32`
5.  **Connection Type:** `WiFi`
6.  Click **Done**.

## Step 2: Configure Datastreams

You need to set up "Datastreams" to link the code to the dashboard widgets. Go to the **Datastreams** tab in your new template and add the following:

| Name | Pin  | Data Type | Units | Min | Max  | Description |
| :--- | :--- | :--- | :--- | :-- | :--- | :--- |
| **Voltage** | `V0` | Double | Volts (V) | 0 | 300  | AC Voltage reading |
| **Current** | `V1` | Double | Amps (A)  | 0 | 30 | AC Current reading |
| **Power** | `V2` | Double | Watts (W) | 0 | 5000 | Total Power consumption |
| **System State** | `V3` | String | None | - | - | Current status (e.g., Normal, Trip) |
| **Reset Button** | `V4` | Integer | None | 0 | 1 | Button to reset system after trip |
| **Manual Switch**| `V5` | Integer | None | 0 | 1 | Manual ON/OFF control switch |
| **Master Override** | `V6` | Integer | None | 0 | 1 | ⚠️ Bypass safety protection (DANGER) |

## Step 3: Create the Web Dashboard (Optional)

1.  Go to the **Web Dashboard** tab.
2.  Drag and drop **Label** or **Gauge** widgets for Voltage, Current, and Power.
3.  Assign them to the datastreams created in Step 2 (`V0`, `V1`, `V2`).
4.  Add a **Label** widget for System State (`V3`).
5.  Add a **Switch** or **Button** widget for Reset (`V4`).

## Step 4: Create the Mobile Dashboard

1.  Open the **Blynk App** on your phone.
2.  Enable **Developer Mode** (if needed) and find your `Energy Monitor` template.
3.  Tap on the template to edit the dashboard.
4.  Add the following widgets:

    - **Gauge** (or Labeled Value) -> Select Datastream: **Voltage (V0)**
    - **Gauge** (or Labeled Value) -> Select Datastream: **Current (V1)**
    - **Gauge** (or Labeled Value) -> Select Datastream: **Power (V2)**
    - **Value Display** -> Select Datastream: **System State (V3)**
    - **Button** -> Select Datastream: **Reset Button (V4)**
      - **Mode:** `Push` (Important!)
    - **Switch** → Select Datastream: **Manual Switch (V5)**
      - **Mode:** `Switch` (toggle ON/OFF)
      - **Label:** "Manual Control"
      - **Description:** "Turn load ON/OFF manually"
    - **Switch** → Select Datastream: **Master Override (V6)**
      - **Mode:** `Switch` (toggle ON/OFF)
      - **Label:** "⚠️ MASTER OVERRIDE"
      - **Description:** "DANGER: Bypasses ALL safety protection!"
      - **Color:** Red (to indicate danger)
      - **⚠️ WARNING**: Only use during maintenance/testing when conditions are known

## ⚠️ Master Override Safety Warning

The Master Override feature **BYPASSES ALL SAFETY PROTECTION** and allows the system to operate outside safe limits. This is **EXTREMELY DANGEROUS** and should only be used:

- During maintenance when you need to test specific conditions
- When you understand the electrical parameters and accept the risks
- For temporary operation while troubleshooting

**When Override is Active:**
- ✅ System operates despite overvoltage/undervoltage/overcurrent
- ✅ LED turns **YELLOW** (solid) to indicate override active
- ✅ Periodic warnings sent every 30 minutes
- ⚠️ **EXCEPTION**: Extreme overcurrent (>150% of max) will still trip for fire prevention
- ⚠️ **RISK**: Equipment damage, fire hazard, electrical shock

**Always disable override when not needed!**

## Step 5: Get Credentials

1.  Save your template.
2.  Go to **Search** (Magnifying glass) -> **+ New Device**.
3.  Select **From Template** -> Choose `Energy Monitor`.
4.  Click **Create**.
5.  You will see a screen with `BLYNK_TEMPLATE_ID`, `BLYNK_TEMPLATE_NAME`, and `BLYNK_AUTH_TOKEN`.
6.  **Copy these values.**

## Step 6: Update the Code

1.  Open `include/config.h` in your project.
2.  Replace the placeholder values with your new credentials:

```cpp
#define BLYNK_TEMPLATE_ID     "TMPLxxxxxx"
#define BLYNK_TEMPLATE_NAME   "Energy Monitor"
#define BLYNK_AUTH_TOKEN      "Your_Auth_Token_Here"
```

3.  **Upload** the code to your ESP32.

## Step 7: Configure Push Notifications

To receive push notifications when the system trips, you MUST configure the event in the Blynk Console:

### 7.1 Create Event in Blynk Console

1.  Log into [Blynk Console](https://blynk.cloud/)
2.  Navigate to **Templates** → Select your template → **Events** tab
3.  Click **"+ Create Event"** (or edit existing `safety_alert` if it exists)
4.  Configure the event:
    - **Event Code**: `safety_alert` (must match exactly)
    - **Event Name**: "Safety Alert" (display name)
    - **Description**: "System trip protection triggered"
    - **Color**: Red (for visibility)
    - **Send push notification**: ✅ **CHECK THIS BOX** (critical!)
    - **Recipients**: Select "Device Owner" or "All Users"
    - **Limit Period**: Set to "No Limit" (for testing) or "1 hour" (for production)
    - **Event Counter**: Leave at default or set to 1
5.  Click **Save**

### 7.2 Enable Notifications in Mobile App

1.  Open the **Blynk IoT** app on your phone
2.  Go to your device
3.  Tap the **Settings** icon (gear icon)
4.  Ensure **"Enable Notifications"** is turned ON
5.  Check your phone's system settings:
    - Go to **Settings** → **Notifications** → **Blynk**
    - Ensure notifications are **Allowed**
    - Turn OFF "Do Not Disturb" mode (if active)

### 7.3 Test Notifications

1.  Trigger a trip event (temporarily lower `VOLTAGE_MAX` in `config.h` to 200V, or disconnect power)
2.  You should receive:
    - **Push notification** on your phone
    - **Timeline entry** in the Blynk app
    - **Email** (if email notifications are also enabled)
3.  If you only see the timeline entry but no push notification, review the troubleshooting section below

## Troubleshooting

### Device Issues
- **Device Offline?** Check your WiFi credentials in `config.h`.
- **No Data?** Ensure the ESP32 is connected to the internet and the Auth Token is correct.
- **Blynk not connecting?** Check serial monitor for connection errors.

### Notification Issues
- **No push notifications but timeline shows events?**
  - Verify "Send push notification" is checked in the event configuration
  - Check phone notification permissions for Blynk app
  - Disable "Do Not Disturb" mode on your phone
  - Try uninstalling and reinstalling the Blynk app
  - Check if you've exceeded the daily notification limit (100 events/day on free plan)

- **Notifications delayed?**
  - Blynk has a 15-second minimum interval between notifications
  - Check the "Limit Period" setting in your event configuration

- **Still not working?**
  - Try enabling **Email notifications** instead (more reliable)
  - Consider implementing a **Telegram Bot** as an alternative notification method
  - Check Blynk community forums for known issues

### Alternative Notification Methods

If Blynk push notifications are unreliable, consider these alternatives:

1.  **Email Notifications** (via Blynk): Enable in the same Events tab, more reliable than push
2.  **Telegram Bot**: Free, reliable, works even when app is closed (requires code modification)
3.  **SMS via Twilio**: Very reliable but requires paid API subscription
4.  **IFTTT Webhooks**: Can trigger notifications to multiple platforms

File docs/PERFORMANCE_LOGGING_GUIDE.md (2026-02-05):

# Performance Evaluation System - Usage Guide

## Overview

The performance evaluation system has been successfully implemented! It measures three critical metrics:

1. **Data Transmission Latency** - Sensor read → Blynk transmission time
2. **Measurement Accuracy** - Voltage/current stability over time
3. **Trip Response Time** - Fault detection → Relay trip time

## Quick Start

### Step 1: Enable Performance Logging

Edit `include/config.h` and uncomment the performance logging flag:

```cpp
// Enable performance logging (uncomment to enable)
#define ENABLE_PERFORMANCE_LOGGING  // <-- Uncomment this line
```

### Step 2: Build and Upload

```bash
# Build the project
pio run

# Upload to ESP32
pio run -t upload
```

### Step 3: Start PC Logger

```bash
# Windows
python tools/performance_logger.py COM11 115200

# Linux/Mac
python tools/performance_logger.py /dev/ttyUSB0 115200
```

**Note:** Replace `COM11` with your actual COM port. Check Device Manager (Windows) or `ls /dev/tty*` (Linux/Mac).

### Step 4: Collect Data

Let the system run for your desired duration:
- **Quick test**: 5-10 minutes
- **Full evaluation**: 1-24 hours
- **Stress test**: Vary loads, trigger faults

You can stop the logger (Ctrl+C) and restart it later - data will continue appending to the same files.

### Step 5: Stop and Analyze

Press `Ctrl+C` in the Python script to stop logging. CSV files are continuously saved in the `performance_data/` directory.

## CSV File Format

### latency.csv

```csv
Timestamp(ms),SensorRead(us),BlynkTransmit(ms),TotalLatency(ms)
1523,245123,15,260
3045,243987,14,258
4567,246234,16,262
```

**Columns:**
- `Timestamp(ms)`: System uptime in milliseconds
- `SensorRead(us)`: Sensor reading time in microseconds
- `BlynkTransmit(ms)`: Blynk transmission time in milliseconds
- `TotalLatency(ms)`: Total latency (sensor + Blynk)

### accuracy.csv

```csv
Timestamp(ms),Voltage(V),Current(A),Power(W)
10234,223.45,5.23,1168.62
20456,223.51,5.21,1164.49
30678,223.48,5.22,1166.57
```

**Columns:**
- `Timestamp(ms)`: System uptime in milliseconds
- `Voltage(V)`: Voltage reading in Volts
- `Current(A)`: Current reading in Amperes
- `Power(W)`: Power reading in Watts

**Logged every 10 seconds** (configurable in `config.h`)

### trip_response.csv

```csv
Timestamp(ms),FaultDetect(us),RelayTrip(us),TotalResponse(ms)
45123,125,85,0.21
```

**Columns:**
- `Timestamp(ms)`: System uptime in milliseconds
- `FaultDetect(us)`: Fault detection time in microseconds
- `RelayTrip(us)`: Relay trip time in microseconds
- `TotalResponse(ms)`: Total response time (detect + trip)

**Logged only when faults occur**

## Analyzing Results

### Using Excel/Google Sheets

1. Open CSV file in Excel/Google Sheets
2. Calculate statistics:
   ```excel
   Average Latency: =AVERAGE(D:D)
   Max Latency: =MAX(D:D)
   Min Latency: =MIN(D:D)
   Std Dev: =STDEV(D:D)
   ```
3. Create graphs:
   - Line chart: Latency over time
   - Line chart: Voltage/Current stability
   - Histogram: Trip response distribution

### Using Python (pandas)

```python
import pandas as pd
import matplotlib.pyplot as plt

# Load data
latency = pd.read_csv('performance_data/latency.csv')
accuracy = pd.read_csv('performance_data/accuracy.csv')

# Calculate statistics
print("Latency Statistics:")
print(latency['TotalLatency(ms)'].describe())

print("\nVoltage Statistics:")
print(accuracy['Voltage(V)'].describe())

# Plot latency over time
plt.figure(figsize=(12, 6))
plt.plot(latency['Timestamp(ms)'], latency['TotalLatency(ms)'])
plt.xlabel('Time (ms)')
plt.ylabel('Latency (ms)')
plt.title('Data Transmission Latency Over Time')
plt.grid(True)
plt.show()

# Plot voltage stability
plt.figure(figsize=(12, 6))
plt.plot(accuracy['Timestamp(ms)'], accuracy['Voltage(V)'])
plt.xlabel('Time (ms)')
plt.ylabel('Voltage (V)')
plt.title('Voltage Stability Over Time')
plt.grid(True)
plt.show()
```

## Performance Targets

### ✅ Success Criteria

| Metric | Target | Acceptable Range |
|---|---|---|
| **Total Latency** | < 100ms | 50-150ms |
| **Sensor Read Time** | < 250ms | 200-300ms |
| **Blynk Transmit** | < 20ms | 10-30ms |
| **Voltage Variation** | < 5% | 2-8% |
| **Current Variation** | < 5% | 2-8% |
| **Trip Response** | < 10ms | 5-15ms |

## Troubleshooting

### Python Script Issues

**Problem:** `ModuleNotFoundError: No module named 'serial'`

**Solution:**
```bash
pip install pyserial
```

**Problem:** `PermissionError: [Errno 13] Permission denied: 'COM3'`

**Solution:**
- Close Arduino IDE or any other program using the serial port
- On Linux: `sudo chmod 666 /dev/ttyUSB0`

**Problem:** No data appearing in CSV files

**Solution:**
- Check that `ENABLE_PERFORMANCE_LOGGING` is uncommented in `config.h`
- Verify ESP32 is running (check for debug output)
- Check baud rate matches (115200)

### ESP32 Issues

**Problem:** Build errors after enabling performance logging

**Solution:**
- Ensure `PerformanceLogger.h` and `PerformanceLogger.cpp` are in correct directories
- Clean build: `pio run -t clean` then `pio run`

**Problem:** High memory usage

**Solution:**
- Performance logging uses minimal memory (~200 bytes)
- If issues persist, disable logging for production use

## Configuration Options

### Accuracy Logging Interval

Edit `include/config.h`:

```cpp
#ifdef ENABLE_PERFORMANCE_LOGGING
    #define PERF_ACCURACY_INTERVAL_MS  10000  // Change to desired interval (ms)
#endif
```

**Recommendations:**
- Fast logging (1 second): `1000` - for short tests
- Normal logging (10 seconds): `10000` - for general use
- Slow logging (1 minute): `60000` - for long-term monitoring

## Test Scenarios

### Baseline Test (10 minutes)

**Purpose:** Establish normal operating parameters

**Procedure:**
1. Enable performance logging
2. Upload to ESP32
3. Run Python logger for 10 minutes
4. No load changes during test

**Expected Results:**
- Stable voltage/current readings
- Consistent latency values
- No trip events

### Load Variation Test (30 minutes)

**Purpose:** Test accuracy under varying loads

**Procedure:**
1. Start with no load
2. Add 10W load at 5 minutes
3. Add 50W load at 15 minutes
4. Remove all loads at 25 minutes

**Expected Results:**
- Current readings should track load changes
- Voltage should remain stable
- Latency should remain consistent

### Fault Response Test

**Purpose:** Measure trip response time

**Procedure:**
1. Enable performance logging
2. Trigger over-voltage condition (if safe)
3. Observe trip response in CSV

**Expected Results:**
- Trip response < 10ms
- Fault detection < 200µs
- Relay trip < 100µs

## Disabling Performance Logging

To disable for production use:

1. Comment out the flag in `config.h`:
   ```cpp
   // #define ENABLE_PERFORMANCE_LOGGING
   ```

2. Rebuild and upload:
   ```bash
   pio run -t upload
   ```

**Note:** All performance logging code is removed at compile time (zero overhead).

## Summary

The performance evaluation system is now fully implemented and ready to use. Simply:

1. ✅ Uncomment `ENABLE_PERFORMANCE_LOGGING` in `config.h`
2. ✅ Build and upload to ESP32
3. ✅ Run `python tools/performance_logger.py COM3 115200`
4. ✅ Analyze CSV files in `performance_data/` directory

For questions or issues, refer to the implementation plan or contact support.

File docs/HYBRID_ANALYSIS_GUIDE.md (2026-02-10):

# Hybrid Performance Analysis Guide 📊

This guide explains how to combine and analyze data from two sources:
1.  **USB Serial Interface**: High-resolution data logged locally to your PC.
2.  **Google Sheets Cloud**: Continuous data logged remotely over WiFi.

---

## 🏗️ System Architecture

```mermaid
graph TD
    ESP32[ESP32 Monitoring Device]
    USB[PC via USB Serial]
    Cloud[Google Sheets Cloud]
    Sync[data_sync.py]
    Analysis[Integrated Analysis]

    ESP32 -->|Real-time| USB
    ESP32 -->|WiFi| Cloud
    USB -->|CSV Files| Sync
    Cloud -->|Fetch| Sync
    Sync -->|Unified Dataset| Analysis
```

---

## 🛠️ Prerequisites

### Python Dependencies
Install the required libraries to handle data processing and cloud communication:
```bash
pip install -r tools/analysis/requirements.txt
```

### Google Apps Script Preparation
Ensure your Apps Script is updated with the latest code from `docs/google_apps_script.js`. This script includes the `doGet` function required for data retrieval.

---

## 🔄 Synchronizing Data

The synchronization process merges cloud data into your local CSV files while automatically handling duplicates (deduplication).

### Running Sync
```bash
python tools/data_sync.py
```

### Troubleshooting Common Errors

#### ❌ `NameResolutionError` / `Failed to resolve 'script.googleusercontent.com'`
- **Cause**: Your computer is having trouble reaching Google's servers.
- **Solution**: 
  - Check your internet connection.
  - Check if you are behind a corporate firewall or VPN that blocks Google Script.
  - Try again after a few minutes; DNS issues are often temporary.

#### ❌ `Cloud error: Sheet not found: TripResponse`
- **Cause**: The script is looking for a tab named exactly "TripResponse" but couldn't find it.
- **Solution**: 
  - Open your Google Sheet.
  - Ensure you have exactly 4 tabs named: `SystemEvents`, `Latency`, `Accuracy`, and `TripResponse`.
  - Check for trailing spaces in the tab names.

---

## 📈 Running the Analysis

Once your data is synced, you can generate comprehensive reports.

### Option 1: Full Automated Workflow
This command will first sync your cloud data and then run all performance reports automatically.
```bash
cd tools/analysis
python integrated_analysis.py
```

### Option 2: Manual Report Generation
If you want to generate the final documentation report after running individual analyses:
```bash
python tools/analysis/generate_report.py
```

---

## 🧩 Data Comparison Matrix

| Metric | Google Sheets (WiFi) | USB Serial (tools/performance_logger.py) |
| :--- | :--- | :--- |
| **Reliability** | Depends on WiFi stability | Depends on USB connection |
| **Outage Coverage** | Stops when WiFi router dies | Continues as long as laptop is ON/Battery |
| **Frequency** | Throttled to save bandwidth | Full speed (up to 10Hz) |
| **Persistence** | Permanent Cloud Storage | Local CSV files |

---

## ✅ Best Practices for Data Quality

1.  **Run Sync Regularly**: Pull cloud data at the end of every testing session.
2.  **Clear Local Files if Corrupted**: If headers get messed up, you can delete the CSVs in `tools/performance_data/` and run `data_sync.py` to restore everything from the cloud.
3.  **Check Heartbeats**: Use the `SystemEvents` tab in Google Sheets to verify the system was up during periods where performance data might be missing.

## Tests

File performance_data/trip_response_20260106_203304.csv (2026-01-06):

DateTime | Uptime(ms) | FaultDetect(us) | RelayTrip(us) | TotalResponse(ms)
2026-01-06 20:33:06 | timestamp | faultDetectUs | relayTripUs | totalResponseMs
2026-01-06 20:35:17 | 132743 | 48 | 11028 | 11
2026-01-06 20:35:41 | 157439 | 48 | 11112 | 11
2026-01-06 20:36:26 | 202387 | 49 | 1391 | 1

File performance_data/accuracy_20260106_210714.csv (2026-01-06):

DateTime | Uptime(ms) | Voltage(V) | Current(A) | Power(W)
2026-01-06 21:07:17 | timestamp | voltage | current | power
2026-01-06 21:07:40 | 24790 | 0.00 | 0.16 | 0.00
2026-01-06 21:07:50 | 34955 | 0.00 | 0.15 | 0.00
2026-01-06 21:08:00 | 45126 | 0.00 | 0.16 | 0.00
2026-01-06 21:08:10 | 55296 | 0.00 | 0.16 | 0.00
2026-01-06 21:08:20 | 65469 | 0.00 | 0.15 | 0.00
2026-01-06 21:08:31 | 75646 | 0.00 | 0.17 | 0.00
2026-01-06 21:08:41 | 85818 | 0.00 | 0.16 | 0.00
2026-01-06 21:08:51 | 95993 | 0.00 | 0.17 | 0.00
2026-01-06 21:09:01 | 106162 | 0.00 | 0.17 | 0.00
2026-01-06 21:09:11 | 116340 | 0.00 | 0.17 | 0.00
2026-01-06 21:09:21 | 126515 | 0.00 | 0.17 | 0.00
2026-01-06 21:09:32 | 136689 | 0.00 | 0.17 | 0.00
2026-01-06 21:09:42 | 146865 | 0.00 | 0.16 | 0.00
2026-01-06 21:09:52 | 157038 | 0.00 | 0.17 | 0.00
2026-01-06 21:10:02 | 167210 | 0.00 | 0.16 | 0.00
2026-01-06 21:10:12 | 177388 | 0.00 | 0.15 | 0.00
2026-01-06 21:10:22 | 187558 | 0.00 | 0.15 | 0.00
2026-01-06 21:10:33 | 197728 | 0.00 | 0.17 | 0.00
2026-01-06 21:10:43 | 207901 | 0.00 | 0.16 | 0.00
2026-01-06 21:10:53 | 218073 | 0.00 | 0.18 | 0.00
2026-01-06 21:11:03 | 228247 | 0.00 | 0.16 | 0.00
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

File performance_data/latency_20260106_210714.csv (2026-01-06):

DateTime | Uptime(ms) | SensorRead(us) | BlynkTransmit(ms) | TotalLatency(ms)
2026-01-06 21:07:17 | timestamp | sensorReadUs | blynkTransmitMs | totalLatencyMs
2026-01-06 21:07:40 | 24789 | 1856233 | 140 | 1996
2026-01-06 21:07:42 | 26823 | 1855998 | 140 | 1995
2026-01-06 21:07:44 | 28853 | 1852731 | 140 | 1992
2026-01-06 21:07:46 | 30887 | 1857711 | 139 | 1996
2026-01-06 21:07:48 | 32922 | 1857535 | 140 | 1997
2026-01-06 21:07:50 | 34954 | 1854527 | 140 | 1994
2026-01-06 21:07:52 | 36988 | 1855998 | 140 | 1995
2026-01-06 21:07:54 | 39023 | 1857452 | 140 | 1997
2026-01-06 21:07:56 | 41057 | 1856388 | 140 | 1996
2026-01-06 21:07:58 | 43091 | 1856710 | 140 | 1996
2026-01-06 21:08:00 | 45125 | 1856674 | 140 | 1996
2026-01-06 21:08:02 | 47160 | 1856165 | 141 | 1997
2026-01-06 21:08:04 | 49196 | 1857442 | 140 | 1997
2026-01-06 21:08:06 | 51228 | 1854463 | 140 | 1994
2026-01-06 21:08:08 | 53261 | 1855492 | 140 | 1995
2026-01-06 21:08:10 | 55295 | 1855518 | 141 | 1996
2026-01-06 21:08:12 | 57329 | 1855990 | 140 | 1995
2026-01-06 21:08:14 | 59364 | 1856645 | 141 | 1997
2026-01-06 21:08:16 | 61398 | 1855661 | 141 | 1996
2026-01-06 21:08:18 | 63433 | 1857496 | 140 | 1997
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

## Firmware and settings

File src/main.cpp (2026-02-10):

/**
 * Smart Energy Monitoring and Safety System
 * 
 * Author: DeeThunder Nexus (Peace_IoT)
 * Website: deethundernexus.org
 * Client: Samuel
 * Date: Dec 1, 2025
 * 
 * Main application file - coordinates all modules through StateManager
 * 
 * Hardware:
 * - ESP32 Dev Kit
 * - ZMPT101b Voltage Sensor (simulated with potentiometer)
 * - SCT-013 Current Sensor (simulated with potentiometer)
 * - 2-Channel Relay Module
 * - SSD1306 OLED Display (I2C)
 * - RGB LED (Common Cathode)
 * - LED(Power indicator)
 * - Physical Boat Switch (Hardware power control, not used in software)
 * - 2 3.7v Li-ion Batteries
 * - 2 18650 Battery Holders
 * - 1 TP4056 Battery Charger Module
 * - 1 Boost Converter Module
 */

#include <Arduino.h>
#include "config.h"
#include "EnergySensor.h"
#include "DisplayManager.h"
#include "SafetyManager.h"
#include "StateManager.h"
#include "NetworkManager.h"

#ifdef ENABLE_PERFORMANCE_LOGGING
    #include "PerformanceLogger.h"
#endif

#ifdef ENABLE_CLOUD_LOGGING
    #include "CloudLogger.h"
#endif

// ============================================================================
// GLOBAL OBJECTS
// ============================================================================

EnergySensor energySensor;
DisplayManager displayManager;
NetworkManager networkManager;
SafetyManager safetyManager;
StateManager stateManager(energySensor, displayManager, networkManager, safetyManager);

#ifdef ENABLE_PERFORMANCE_LOGGING
    PerformanceLogger perfLogger;
#endif

#ifdef ENABLE_CLOUD_LOGGING
    CloudLogger cloudLogger;
#endif

// ============================================================================
// SETUP
// ============================================================================

void setup() {
    // Initialize serial communication
    #ifdef APP_DEBUG
        Serial.begin(115200);
        delay(1000);  // Only delay in setup for serial stability
        Serial.println("========================================");
        Serial.println("Smart Energy Monitoring System");
        Serial.println("========================================\n");
    #endif
    
    // ============================================================================
    // DIAGNOSTIC MODE - If enabled, run current sensor diagnostics only
    // ============================================================================
    #ifdef ENABLE_CURRENT_DIAGNOSTIC
        setupCurrentDiagnostic();  // This will run in an infinite loop
        // Code below will never execute when diagnostic mode is enabled
    #endif
    
    // Initialize all modules
    #ifdef APP_DEBUG
        Serial.println("[Main] Initializing modules...");
    #endif
    
    energySensor.begin();
    safetyManager.begin();
    
    if (!displayManager.begin()) {
        #ifdef APP_DEBUG
            Serial.println("[Main] WARNING: Display initialization failed!");
        #endif
    }
    
    networkManager.begin();
    
    // Register reset callback for Blynk button
    networkManager.setResetCallback([]() {
        stateManager.handleReset();
    });
    
    // Register manual switch callback for Blynk switch
    networkManager.setManualSwitchCallback([](bool turnOn) {
        stateManager.handleManualSwitch(turnOn);
    });
    
    // Register master override callback for Blynk switch
    networkManager.setMasterOverrideCallback([](bool enable) {
        stateManager.handleMasterOverride(enable);
    });
    
    stateManager.begin();
    
    #ifdef ENABLE_PERFORMANCE_LOGGING
        perfLogger.begin();
        Serial.println("[Main] Performance logging ENABLED");
        Serial.println("[Main] Run: python tools/performance_logger.py COM3 115200");
    #endif

    #ifdef ENABLE_CLOUD_LOGGING
        cloudLogger.begin();
    #endif
    
    #ifdef APP_DEBUG
        Serial.println("Safety Thresholds:");
        Serial.printf("  Voltage: %.1fV - %.1fV\n", VOLTAGE_MIN, VOLTAGE_MAX);
        Serial.printf("  Current: 0A - %.1fA\n\n", CURRENT_MAX);
    #endif
}

// ============================================================================
// MAIN LOOP
// ============================================================================

void loop() {
    // Update state machine (handles all module coordination)
    stateManager.update();
    // Small yield to prevent watchdog timeout
    yield();

    #ifdef ENABLE_CLOUD_LOGGING
        cloudLogger.update();
    #endif
}

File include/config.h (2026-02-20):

// ============================================================================
// SECRETS - MUST BE INCLUDED FIRST
// ============================================================================
// Copy secrets.h.example to secrets.h and fill in your credentials
#include "secrets.h"

// ============================================================================
// BLYNK CONFIGURATION (Must be defined BEFORE including Blynk library)
// ============================================================================
#define BLYNK_TEMPLATE_ID SECRET_BLYNK_TEMPLATE_ID
#define BLYNK_TEMPLATE_NAME SECRET_BLYNK_TEMPLATE_NAME
#define BLYNK_AUTH_TOKEN SECRET_BLYNK_AUTH_TOKEN

#ifndef CONFIG_H
#define CONFIG_H

// ============================================================================
// PIN DEFINITIONS
// ============================================================================

// Analog Sensors (ADC1 only - ADC2 conflicts with WiFi)
#define PIN_VOLTAGE_SENSOR    34  // ADC1_CH6 - Voltage sensor (ZMPT101b / Potentiometer)
#define PIN_CURRENT_SENSOR    35  // ADC1_CH7 - Current sensor (SCT-013 / Potentiometer)

// Digital Outputs
#define PIN_RELAY             26  // Relay control (GPIO23 is safe and reliable)
#define PIN_RGB_RED           25  // RGB LED - Red channel
#define PIN_RGB_GREEN         33  // RGB LED - Green channel
#define PIN_RGB_BLUE          32  // RGB LED - Blue channel

// Digital Inputs
// Note: Physical boat switch controls hardware power to ESP32, not used in software

// I2C (OLED Display)
#define PIN_SDA               21  // I2C Data
#define PIN_SCL               22  // I2C Clock

// ============================================================================
// HARDWARE CONFIGURATION
// ============================================================================

// Relay Configuration

// LOW = Relay energizes (ON), HIGH = Relay de-energizes (OFF)
#define RELAY_ACTIVE_HIGH     false

// RGB LED Configuration
#define RGB_COMMON_CATHODE    true   // Set to false if Common Anode

// OLED Display Configuration
#define SCREEN_WIDTH          128
#define SCREEN_HEIGHT         64
#define OLED_RESET            -1     // Reset pin (-1 if sharing Arduino reset pin)
#define SCREEN_ADDRESS        0x3C   // I2C address (0x3C or 0x3D)

// ============================================================================
// WIFI CONFIGURATION
// ============================================================================

// WiFi Credentials (defined in secrets.h)
#define WIFI_SSID             SECRET_WIFI_SSID
#define WIFI_PASSWORD         SECRET_WIFI_PASSWORD

// Blynk Virtual Pins
#define VPIN_VOLTAGE          V0     // Voltage reading
#define VPIN_CURRENT          V1     // Current reading
#define VPIN_POWER            V2     // Power reading
#define VPIN_STATE            V3     // System state (string)
#define VPIN_RESET_BUTTON     V4     // Reset button (write)
#define VPIN_MANUAL_SWITCH    V5     // Manual ON/OFF switch (write)
#define VPIN_MASTER_OVERRIDE  V6     // Master override switch (WEB ONLY)

// ============================================================================
// SAFETY THRESHOLDS
// ============================================================================

// Voltage Thresholds (in Volts)
#define VOLTAGE_MAX           255.0  // Over-voltage trip threshold
#define VOLTAGE_MIN           185.0  // Under-voltage trip threshold
#define VOLTAGE_HYSTERESIS    5.0    // Hysteresis to prevent relay chattering
#define VOLTAGE_POWER_PRESENT_THRESHOLD 100.0  // Below this = power is off

// Current Thresholds (in Amperes)
#define CURRENT_MAX           30.0   // Over-current trip threshold
#define CURRENT_HYSTERESIS    0.5    // Hysteresis to prevent relay chattering

// ============================================================================
// CALIBRATION CONSTANTS
// ============================================================================
// 
// HOW TO CALIBRATE PROPERLY:
// 2. Measure actual mains voltage with multimeter
// 3. Check serial output for "Voltage RMS: X.XXXXV" (this is rmsVoltage)
// 4. Calculate: VOLTAGE_CALIBRATION_FACTOR = Multimeter_Reading / rmsVoltage

#define VOLTAGE_CALIBRATION_FACTOR  520 // TODO: Calibrate using method above
#define VOLTAGE_ZERO_POINT          2.19   // VCC/2 for ZMPT101B (adjust if needed)
#define VOLTAGE_NOISE_THRESHOLD     75.0   // Ignore readings below this (ghost voltage)

// Voltage Sensor Sampling Parameters (for stability)
#define VOLTAGE_NUM_SAMPLES         2000   // Samples per reading (~400ms, covers 20 AC cycles @ 50Hz)
#define VOLTAGE_NUM_READINGS        5      // Multiple readings for median filtering
#define VOLTAGE_SAMPLE_DELAY_US     200    // Microseconds between samples (5kHz sampling rate)
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

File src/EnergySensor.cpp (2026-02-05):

#include "EnergySensor.h"
#include "config.h"
#include <math.h>

#ifdef ENABLE_PERFORMANCE_LOGGING
    #include "PerformanceLogger.h"
#endif

EnergySensor::EnergySensor() 
    : voltage_(0.0), current_(0.0), simulationMode_(true) {
}

void EnergySensor::begin() {
    // Configure ADC pins as input
    pinMode(PIN_VOLTAGE_SENSOR, INPUT);
    pinMode(PIN_CURRENT_SENSOR, INPUT);
    
    // Set ADC resolution to 12-bit for better precision
    analogReadResolution(12);
    
    // Set ADC attenuation for 0-3.3V range
    analogSetAttenuation(ADC_11db);  // 0-3.3V range
    
    #ifdef SIMULATION_MODE
        simulationMode_ = true;
        #ifdef APP_DEBUG
            Serial.println("[EnergySensor] Initialized in SIMULATION mode");
        #endif
    #else
        simulationMode_ = false;
        #ifdef APP_DEBUG
            Serial.printf("[EnergySensor] Current calibration factor: %.1f\n", CURRENT_CALIBRATION_FACTOR);
        #endif
        // Initialize EmonLib for current sensing
        // SCT-013-100: 100A/1V sensor with voltage divider
        emon1_.current(PIN_CURRENT_SENSOR, CURRENT_CALIBRATION_FACTOR);
    #endif
}

void EnergySensor::update() {
    #ifdef ENABLE_PERFORMANCE_LOGGING
        extern PerformanceLogger perfLogger;
        perfLogger.startSensorRead();
    #endif
    
    if (simulationMode_) {
        // Read Raw Values
        float rawVoltage = readVoltageSimulation();
        float rawCurrent = readCurrentSimulation();
        
        if (rawVoltage < VOLTAGE_NOISE_THRESHOLD) {
            // Power is OFF - reset immediately
            voltage_ = 0.0;
            current_ = 0.0;
        } else {
            // Power is ON - use median-filtered values directly
            voltage_ = rawVoltage;
            
            // Current: reset to 0 if below threshold, otherwise use raw value
            if (rawCurrent == 0.0 || rawCurrent < CURRENT_NOISE_THRESHOLD) {
                current_ = 0.0;
            } else {
                current_ = rawCurrent;
            }
        }
        
    } else {
        #ifndef SIMULATION_MODE
            // Production mode: Use EmonLib for current, simulation for voltage
            voltage_ = readVoltageSimulation();
            
            // Take multiple samples and average for stability
            double sum = 0;
            for (int i = 0; i < CURRENT_NUM_AVERAGES; i++) {
                double Irms = emon1_.calcIrms(CURRENT_EMON_SAMPLES);
                sum += Irms;
                delay(100); // Small delay between samples
            }
            double avgCurrent = sum / CURRENT_NUM_AVERAGES;
            
            // Basic noise floor removal
            if (avgCurrent < CURRENT_NOISE_THRESHOLD) {
                avgCurrent = 0;
            }
            
            current_ = avgCurrent;
            
            #ifdef APP_DEBUG
                Serial.printf("[EnergySensor] EmonLib Current: %.2f A\n", current_);
            #endif
        #endif
    }
    
    #ifdef ENABLE_PERFORMANCE_LOGGING
        perfLogger.endSensorRead();
    #endif
    
    #ifdef DEBUG_SERIAL
        Serial.printf("[EnergySensor] V=%.2fV, I=%.2fA, P=%.2fW\n", 
                      voltage_, current_, getPower());
    #endif
}

float EnergySensor::getVoltage() const {
    return voltage_;
}

float EnergySensor::getCurrent() const {
    return current_;
}

float EnergySensor::getPower() const {
    return voltage_ * current_;
}

void EnergySensor::setSimulationMode(bool enable) {
    simulationMode_ = enable;
    #ifdef DEBUG_SERIAL
        Serial.printf("[EnergySensor] Simulation mode: %s\n", 
                      enable ? "ENABLED" : "DISABLED");
    #endif
}

bool EnergySensor::isValid() const {
    // Check if readings are within reasonable bounds
    return (voltage_ >= 0 && voltage_ <= 300) && 
           (current_ >= 0 && current_ <= 100);
}

uint16_t EnergySensor::readADC(uint8_t pin) {
    uint32_t sum = 0;
    
    // Take multiple samples and average
    for (int i = 0; i < ADC_SAMPLES; i++) {
        sum += analogRead(pin);
        delayMicroseconds(100);  // Small delay between samples
    }
    
    return sum / ADC_SAMPLES;
}

float EnergySensor::applyCalibration(uint16_t rawValue, float slope, float intercept) {
    return (rawValue * slope) + intercept;
}

float EnergySensor::readVoltageSimulation() {
    // ZMPT101B AC voltage sensor reading using Enhanced True RMS
    // Improvements for stability:
    // 1. More samples to cover multiple complete AC cycles (50Hz = 20ms period)
    // 2. Proper timing to avoid aliasing
    // 3. Multiple readings with median filtering to reject outliers
    // 4. Moving average for smooth output
    
    const int numSamples = 2000;  // ~400ms at 200μs = 20 AC cycles @ 50Hz
    const int numReadings = 5;    // Take 5 readings and use median
    const float vRef = 3.3;       // ESP32 ADC reference voltage
    
    float readings[numReadings];
    
    // Take multiple RMS readings
    for (int reading = 0; reading < numReadings; reading++) {
        unsigned long sumRaw = 0;
        double sumSqRaw = 0; // Double precision for squares to avoid overflow
        
        // Single Sampling Pass - cover multiple AC cycles
        for (int i = 0; i < numSamples; i++) {
            uint16_t rawADC = analogRead(PIN_VOLTAGE_SENSOR);
            sumRaw += rawADC;
            sumSqRaw += (double)rawADC * rawADC;
            // 200μs delay = 5000 samples/sec, well above Nyquist for 50Hz
            delayMicroseconds(200);
        }
        
        // 1. Calculate Mean (DC Bias)
        double mean = (double)sumRaw / numSamples;
        
        // 2. Calculate Variance of the counts (E[x^2] - (E[x])^2)
        // This gives us the Mean Square of the AC component
        double meanSquareRaw = (sumSqRaw / numSamples) - (mean * mean);
        
        // Handle floating point errors (negative zero)
        if (meanSquareRaw < 0) meanSquareRaw = 0;
        
        // 3. RMS in ADC counts
        double rmsADC = sqrt(meanSquareRaw);
        
        // 4. Convert to Voltage
        float rmsVoltage = (float)((rmsADC / ADC_RESOLUTION) * vRef);
        
        // Store this reading
        readings[reading] = rmsVoltage;
        
        // Small delay between readings
        delay(10);
    }
    
    // Sort readings to find median (simple bubble sort for small array)
    for (int i = 0; i < numReadings - 1; i++) {
        for (int j = 0; j < numReadings - i - 1; j++) {
            if (readings[j] > readings[j + 1]) {
                float temp = readings[j];
                readings[j] = readings[j + 1];
                readings[j + 1] = temp;
            }
        }
    }
    
    // Use median value (middle element) - most stable, rejects outliers
    float rmsVoltage = readings[numReadings / 2];
    
    // Apply calibration factor
    float actualVoltage = rmsVoltage * VOLTAGE_CALIBRATION_FACTOR;
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

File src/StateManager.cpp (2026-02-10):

#include "StateManager.h"
#include "NetworkManager.h"
#include "config.h"

#ifdef ENABLE_PERFORMANCE_LOGGING
    #include "PerformanceLogger.h"
#endif

#ifdef ENABLE_CLOUD_LOGGING
    #include "CloudLogger.h"
    extern CloudLogger cloudLogger;
#endif

StateManager::StateManager(EnergySensor& sensor, DisplayManager& display, 
                           NetworkManager& network, SafetyManager& safety)
    : sensor_(sensor), display_(display), network_(network), safety_(safety),
      currentState_(STATE_BOOT), previousState_(STATE_BOOT),
      stateEntryTime_(0), lastSensorRead_(0), lastDisplayUpdate_(0),
      lastSafetyCheck_(0),
      blynkWasConnected_(false), powerOutageNotified_(false),
      faultNotified_(false), powerWasPresent_(true),
      lastNotificationTime_(0), isManuallyOff_(false),
      isOverrideActive_(false), lastOverrideWarning_(0) {
}

// Minimum time between notifications to avoid Blynk rate limits
const unsigned long NOTIFICATION_INTERVAL_MS = 1000;

void StateManager::loadSavedStates() {
    isOverrideActive_ = preferences_.getBool(PREF_OVERRIDE_ACTIVE, false);
    isManuallyOff_ = preferences_.getBool(PREF_MANUAL_OFF, false);
    
    #ifdef APP_DEBUG
        Serial.printf("[StateManager] Loaded states: Override=%d, ManualOff=%d\n", 
                      isOverrideActive_, isManuallyOff_);
    #endif
}

void StateManager::saveOverrideState(bool active) {
    preferences_.putBool(PREF_OVERRIDE_ACTIVE, active);
    
    #ifdef APP_DEBUG
        Serial.printf("[StateManager] Saved override state: %d\n", active);
    #endif
}

void StateManager::saveManualSwitchState(bool manualOff) {
    preferences_.putBool(PREF_MANUAL_OFF, manualOff);
    
    #ifdef APP_DEBUG
        Serial.printf("[StateManager] Saved manual switch state: %d\n", manualOff);
    #endif
}

void StateManager::begin() {
    // Initialize preferences
    preferences_.begin(PREF_NAMESPACE, false);  // false = read/write mode
    
    #ifdef APP_DEBUG
        Serial.println("[StateManager] Preferences initialized");
    #endif
    
    // Load saved states from non-volatile storage
    loadSavedStates();
    
    // Set initial state
    setState(STATE_BOOT);
    
    // Restore override state if it was active before power loss
    if (isOverrideActive_) {
        #ifdef APP_DEBUG
            Serial.println("[StateManager] Restoring override state from memory");
        #endif
        
        // Re-enable override (without notification during boot)
        safety_.clearFault();
        safety_.resetRelay();
        safety_.setRGBStatus(RGB_YELLOW);
        // Note: V5 sync will happen after network connects
    }
    
    // Restore manual OFF state if it was set before power loss
    if (isManuallyOff_) {
        #ifdef APP_DEBUG
            Serial.println("[StateManager] Restoring manual OFF state from memory");
        #endif
        
        safety_.tripRelay();
        safety_.setRGBStatus(RGB_ORANGE);
        safety_.setBlinking(true);
        // Note: V5 sync will happen after network connects
    }
    
    // Set up power state change callback for notifications
    safety_.powerStateCallback = [this](bool powerPresent) {
        unsigned long now = millis();
        // Simple throttle check
        bool canSend = (now - lastNotificationTime_ >= NOTIFICATION_INTERVAL_MS);
        
        if (powerPresent) {
            // Power restored
            powerOutageNotified_ = false;  // Reset for next outage
            if (network_.isBlynkConnected() && canSend) {
                network_.sendAlert("POWER RESTORED: Mains voltage detected");
                lastNotificationTime_ = now;
            }
            
            #ifdef ENABLE_CLOUD_LOGGING
                cloudLogger.logSystemEvent("POWER_RESTORED", "Mains voltage detected - Running on AC power");
            #endif
            
            // Note: If throttled, we might miss "POWER RESTORED", but 3s debounce makes collision rare.
            // "POWER OUTAGE" is the critical one to ensure we catch up.
        } else {
            // Power outage
            if (network_.isBlynkConnected() && canSend) {
                network_.sendAlert("POWER OUTAGE: Mains voltage lost");
                powerOutageNotified_ = true;
                lastNotificationTime_ = now;
            } else {
                // Not connected OR throttled - mark as not notified so update() can catch up
                powerOutageNotified_ = false;
            }
            
            #ifdef ENABLE_CLOUD_LOGGING
                cloudLogger.logSystemEvent("POWER_OUTAGE", "Mains voltage lost - Running on battery");
            #endif
        }
        powerWasPresent_ = powerPresent;
    };
    
    #ifdef APP_DEBUG
        Serial.println("[StateManager] Initialized");
    #endif
}

void StateManager::update() {
    // Detect Blynk reconnection edge
    bool blynkConnected = network_.isBlynkConnected();
    bool reconnectionEdge = blynkConnected && !blynkWasConnected_;
    blynkWasConnected_ = blynkConnected;
    
    // Sync-on-Reconnect Logic
    if (reconnectionEdge) {
        #ifdef APP_DEBUG
            Serial.println("[StateManager] Blynk connection detected - verifying status for catch-up alerts");
        #endif
        
        unsigned long now = millis();
        // Check if we can send notification now
        if (now - lastNotificationTime_ >= NOTIFICATION_INTERVAL_MS) {
            
            // 1. Check Power Status
            if (!safety_.isPowerPresent() && !powerOutageNotified_) {
                network_.sendAlert("POWER OUTAGE: Mains voltage lost");
                powerOutageNotified_ = true;
                lastNotificationTime_ = now;
                #ifdef APP_DEBUG
                    Serial.println("[StateManager] Catch-up: Sent POWER OUTAGE alert");
                #endif
                return; // Only send one alert per loop to respect rate limit
            }
            
            // 2. Check Fault Status
            if (currentState_ == STATE_TRIP_PROTECTION && !faultNotified_) {
                network_.sendAlert(safety_.getLastFaultReason());
                faultNotified_ = true;
                lastNotificationTime_ = now;
                #ifdef APP_DEBUG
                    Serial.printf("[StateManager] Catch-up: Sent fault alert: %s\n", 
                                   safety_.getLastFaultReason().c_str());
                #endif
            }
        }
    }
    
    // Execute current state logic
    switch (currentState_) {
        case STATE_BOOT:
            updateStateBoot();
            break;
        case STATE_NORMAL:
            updateStateNormal();
            break;
        case STATE_TRIP_PROTECTION:
            updateStateTripProtection();
            break;
        case STATE_OFFLINE_MODE:
            updateStateOfflineMode();
            break;
    }
}
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

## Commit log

2025-12-19 fixed calibrations
2025-12-29 fixing sct-013 and relay logic
    [DisplayManager.cpp, EnergySensor.cpp, NetworkManager.cpp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]
2026-01-06 fixed current clib
2026-01-06 added performance logging
    [accuracy_20260106_203304.csv, accuracy_20260106_210714.csv, latency_20260106_203304.csv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]
2026-02-02 added project docs and ignored
    [Samuel's Project.fzz]
2026-02-02 Remove docs folder from Git tracking and add to gitignore
    [Samuel's Project.fzz]
2026-02-05 updated logging, docs and claibration factor
    [accuracy.csv, accuracy_20260106_203304.csv, latency.csv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]
2026-02-05 calibration work flow
2026-02-05 UPDATED NOTOFICATION AND ANALYSIS
    [accuracy.csv, latency.csv, trip_response.csv]
2026-02-20 updated relay logic
